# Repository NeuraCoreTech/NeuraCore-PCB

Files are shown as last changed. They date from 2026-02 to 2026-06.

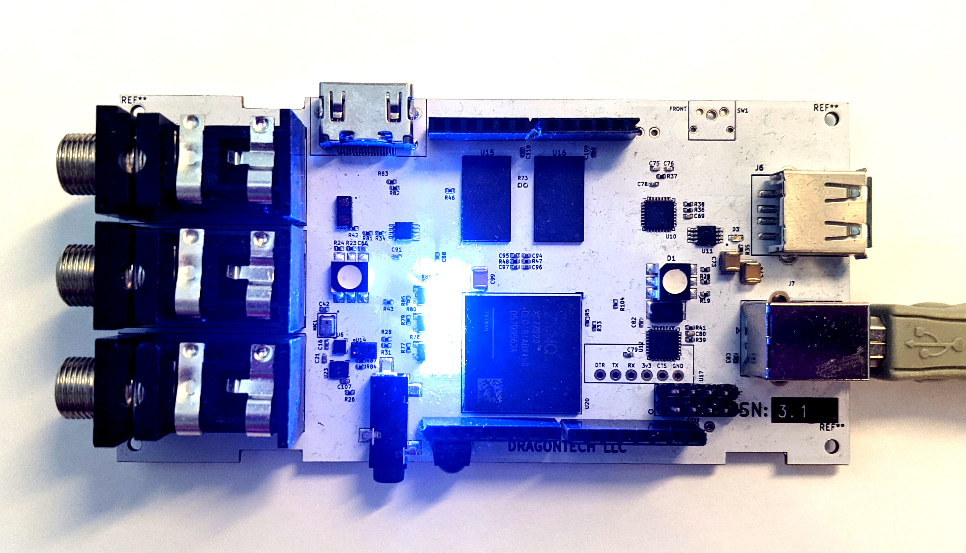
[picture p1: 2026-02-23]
V01/zynqPCB/images/dt01_v3_top.jpg

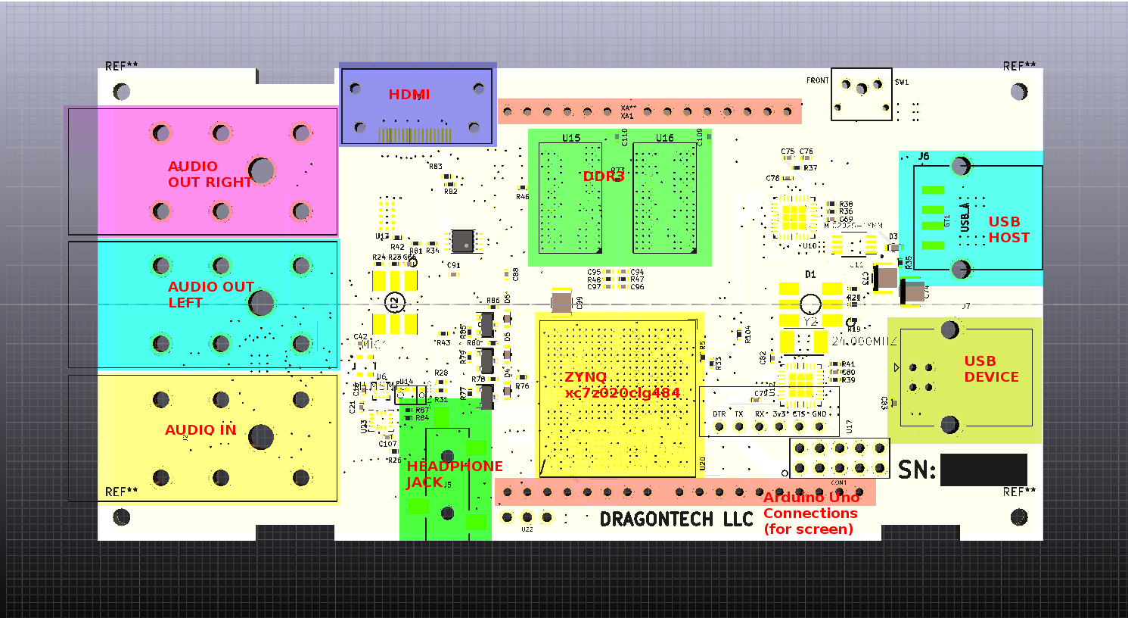
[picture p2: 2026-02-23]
V01/zynqPCB/images/blockdiagram_edited.png

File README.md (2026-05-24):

# FPGA Dev Board - Xilinx XC7Z020

Custom Zynq-7000 FPGA + ARM SoC development board based on the Xilinx XC7Z020-1CLG484I.

This repository contains the PCB design files, schematics, BOM, and hardware documentation for the board.

---

## Overview

This board is designed as a general-purpose Zynq development platform featuring:

- Xilinx XC7Z020 SoC
- DDR3L memory subsystem
- Gigabit Ethernet
- USB programming and UART interface
- USB OTG support
- QSPI boot flash
- Multi-rail power architecture
- FPGA PL expansion banks

The design targets embedded Linux, FPGA acceleration, digital design experimentation, and hardware/software co-design workflows.

---

## Hardware Features

### Processing System
- Xilinx XC7Z020-1CLG484I
- Dual-core ARM Cortex-A9
- FPGA programmable logic fabric

### Memory
- DDR3L memory interface
- Fly-by routed DDR topology
- Dedicated VTT termination rail

### Power Architecture
Power rails:
- 5V Input
- 3.3V
- 1.8V
- 1.35V
- 1.0V
- 0.675V DDR termination

Power sequencing implemented using:
- TPS56628 buck converters
- Dedicated PG sequencing
- Protection and filtering stages

### Connectivity
- Gigabit Ethernet (RTL8211F PHY)
- USB-C programming interface
- USB OTG via USB3320 ULPI PHY
- FT2232H for JTAG + UART

### Boot & Programming
- QSPI flash boot support
- Boot mode DIP switches
- Digilent HS3 compatible JTAG header

### FPGA I/O
- PL banks exposed for expansion
- HDMI-capable bank preparation
- Mixed-voltage IO support

---

## Repository Structure

```text
.
├── schematic/
├── pcb/
├── bom/
├── manufacturing/
├── images/
└── README.md
```

---

## Design Files

| File | Description |
|---|---|
| Schematic PDF | Complete board schematic |
| BOM | Bill of materials |
| PCB Layout | Board routing and placement |
| Gerbers | Manufacturing outputs |

---

## Key Components

| Component | Part |
|---|---|
| SoC | XC7Z020-1CLG484I |
| DDR3L | MT41K256M16TW |
| Ethernet PHY | RTL8211F-CG |
| USB PHY | USB3320 |
| USB/JTAG Interface | FT2232HL |
| QSPI Flash | W25Q512JVEIQ |

---

## Development Status

Current revision:
- v0.07

Status:
- Hardware prototype
- Under validation/testing

Known improvements and future revisions are documented within the schematic notes.

---

## Toolchain

Designed using:
- EasyEDA

Firmware/software targets:
- Vivado
- Vitis
- PetaLinux

---

## Bring-Up Checklist

- [ ] Verify all power rails
- [ ] Validate power sequencing
- [ ] DDR memory calibration
- [ ] QSPI boot validation
- [ ] JTAG connectivity test
- [ ] Ethernet PHY validation
- [ ] USB OTG validation

---

## Manufacturing Notes

Before fabrication:
- Verify impedance-controlled traces
- Review DDR length matching
- Validate power plane integrity
- Confirm connector footprints
- Review DFM constraints

---

## Contributors

- Krishna H. Patil
- Mohit Singh 
- Prajwal
- Arnav Yadnopavit

---
## Acknowledgements

This part of project (PCB) is heavily based on the open-source Zynq-7000 FPGA development board work by rehsd.

Original reference project:
https://github.com/rehsd/FPGA

Additional documentation and development notes:
https://www.rehsdonline.com/

The hardware architecture, schematic structure, and several subsystem implementations were adapted from the original project and modified for NeuraCoreTech requirements.

We thank rehsd for openly publishing the design resources and documentation.

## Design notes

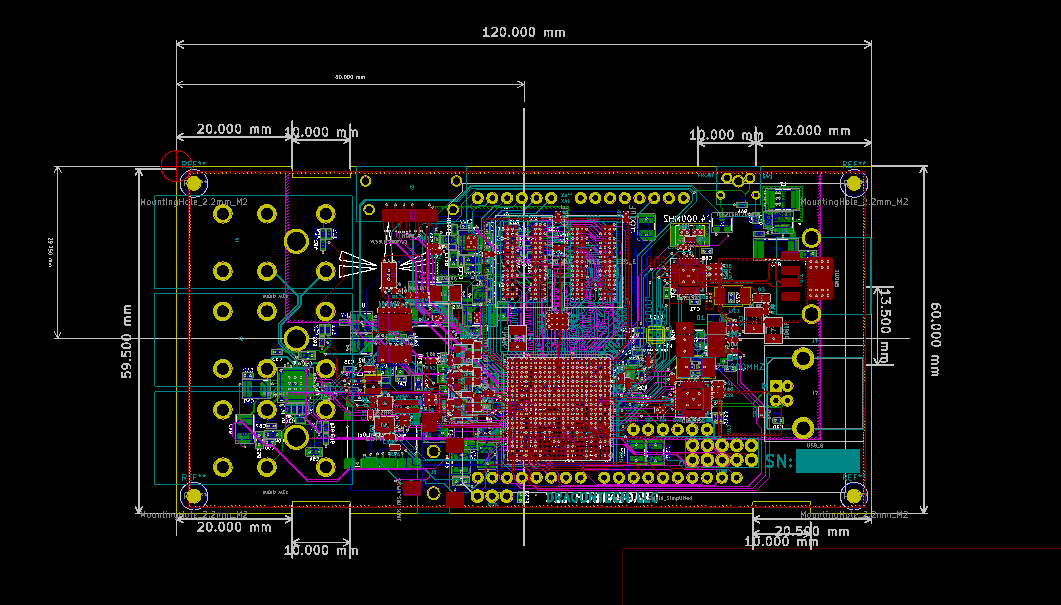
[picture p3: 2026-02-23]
V01/zynqPCB/images/dt01_schematic.PNG

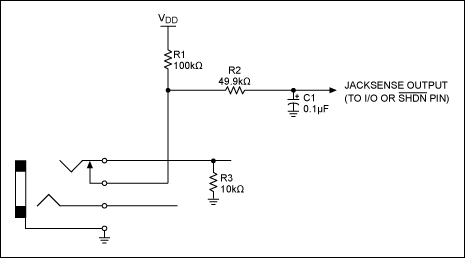
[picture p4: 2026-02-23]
V01/zynqPCB/docs/jackdetection.gif

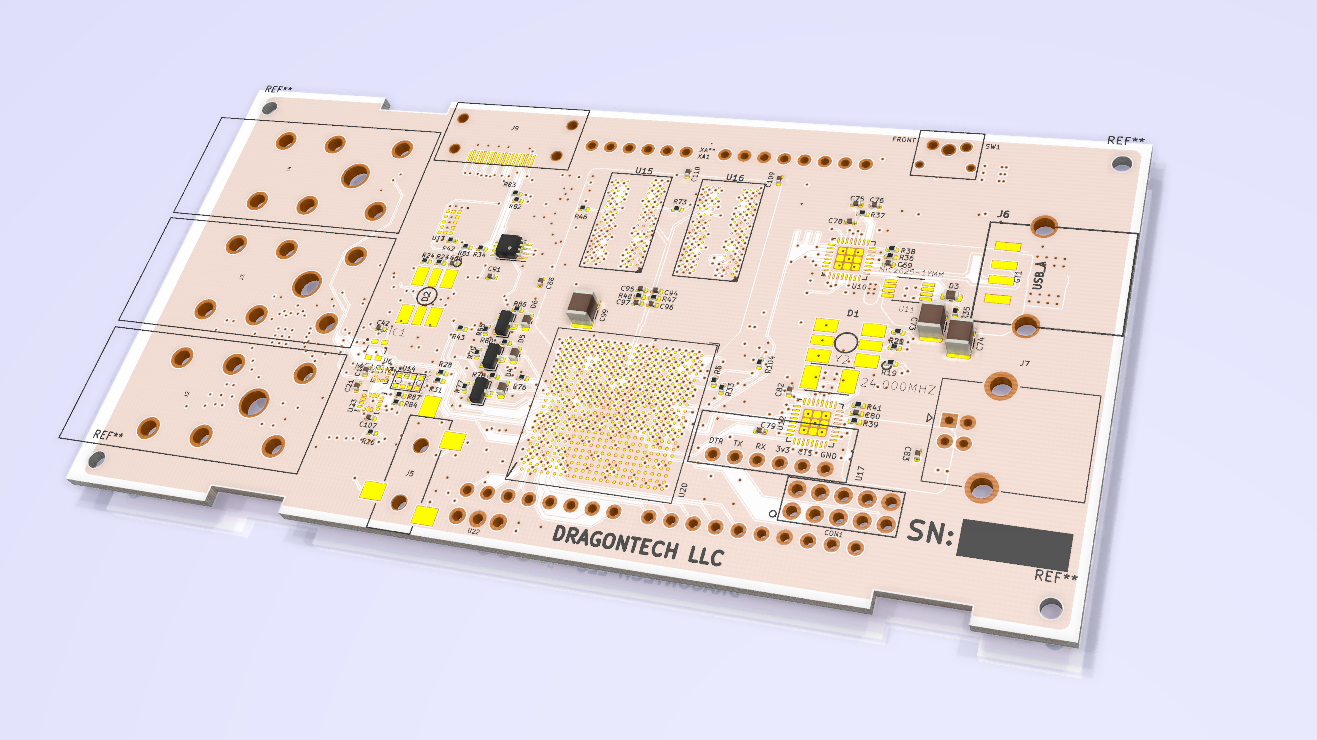
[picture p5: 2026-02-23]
V01/zynqPCB/images/dt01_3drender.PNG

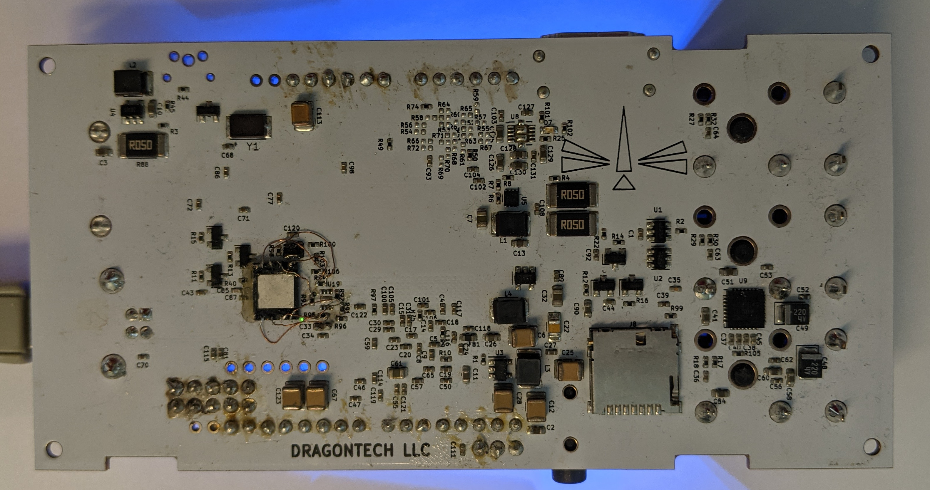
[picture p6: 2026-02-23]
V01/zynqPCB/images/dt01_v3_bottom.jpg

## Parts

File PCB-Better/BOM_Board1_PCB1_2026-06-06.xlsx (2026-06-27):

No. | Quantity | Comment | Designator | Footprint | Value | Manufacturer Part | Manufacturer | Supplier Part | Supplier
1 | 24 | 100nF | C1,C2,C3,C7,C12,C15,C20,C22,C23,C28,C31,C32,C144,C176,C183,C190,C191,C192,C193,C194,C195,C240,C241,C243 | C0603 | 100nF | C0603C104J5RAC | KEMET(基美) | C490602 | LCSC
2 | 53 | 4.7uF | C4,C5,C8,C13,C14,C19,C27,C30,C34,C42,C45,C46,C49,C52,C55,C58,C60,C62,C65,C73,C77,C78,C83,C85,C90,C91,C92,C93,C94,C155,C157,C159,C166,C168,C170,C181,C182,C184,C189,C218,C219,C221,C222,C227,C228,C229,C230,C244,C277,C278,C279,C280,C300 | C0603 | 4.7uF | CC0603KRX5R8BB475 | YAGEO(国巨) | C326580 | LCSC
3 | 6 | 47nF | C6,C35,C36,C37,C38,C39 | C0603 | 47nF
4 | 8 | 22uF | C9,C16,C17,C24,C25,C33,C217,C220 | C0603 | 22uF
5 | 4 | 10uF | C10,C11,C18,C26 | C0603 | 10uF
6 | 1 | 47pF | C21 | C0603 | 47pF
7 | 1 | 150pF | C29 | C0603 | 150pF
8 | 36 | 47nF | C40,C41,C43,C44,C48,C50,C51,C53,C54,C56,C57,C59,C63,C64,C66,C67,C68,C69,C70,C71,C80,C81,C82,C84,C86,C87,C88,C89,C96,C97,C98,C99,C100,C101,C102,C103 | C0402 | 47nF
9 | 22 | 470nF | C47,C61,C72,C74,C75,C76,C79,C95,C259,C264,C265,C268,C284,C285,C286,C293,C294,C295,C301,C302,C359,C360 | C0402 | 470nF
10 | 1 | 330uF | C248 | CAP-SMD_L7.3-W4.3-L-FD | 330uF | 10TPB330M | PANASONIC(松下) | C347551 | LCSC
11 | 10 | 100uF | C253,C257,C258,C262,C263,C287,C288,C289,C290,C291 | CAP-SMD_L3.5-W2.8-FD |  | 100uF | 湘怡中元/湘江 | C18185992 | LCSC
12 | 2 | 47uF | C261,C274 | CAP-SMD_L3.5-W2.8-FD |  | 47uF | 湘怡中元/湘江 | C18185992 | LCSC
13 | 16 | 100nF | C303,C349,C350,C351,C352,C353,C354,C355,C356,C357,C358,C361,C362,C363,C364,C365 | C0402 | 100nF
14 | 1 | 1nF 250V | C348 | C1206 | 1nF 250V | CC1206KRX7RYBB102 | YAGEO(国巨) |  | LCSC
15 | 14 | 100nF | C366,C367,C368,C369,C370,C371,C372,C373,C374,C375,C376,C377,C378,C379 | C0402 | 100nF |  |  | C1525
16 | 25 | 470nF | C380,C381,C382,C383,C384,C385,C386,C387,C388,C389,C390,C391,C392,C393,C394,C395,C396,C397,C398,C399,C400,C401,C402,C403,C404 | C0201 | 470nF | GRM033R60J474KE90D | muRata(村田) | C85926 | LCSC
17 | 1 | 100nF | C406 | C0201 | 100nF | CC0201KRX5R7BB104 | YAGEO(国巨) | C467016 | LCSC
18 | 1 | TF-01A | CARD2 | TF-SMD_TF-02 |  | TF-01A | Yuandi(元迪) | C2889258 | LCSC
19 | 1 | 10029449-111RLF | CN2 | HDMI-SMD_10029449-001RLF |  | 10029449-111RLF | Amphenol | C427307 | LCSC
20 | 9 | Zener Diode | D1,D2,D3,D4,D6,D7,D9,D10,D11 | D0402
21 | 3 | PMEG1030EJ,115 | D8,D12,D13 | SOD-323_L1.8-W1.3-LS2.5-RD |  | PMEG1030EJ,115 | Nexperia(安世) | C133633 | LCSC
22 | 1 | DC-005_2.0 | DC1 | DC-IN-TH_DC-5520-1
23 | 1 | 1206L050/15YR | F1 | F1206 |  | 1206L050/15YR | Littelfuse(美国力特) | C151162 | LCSC
24 | 1 | PTSLR12106V350 | F2 | F1210
25 | 2 | HDR | H2,H3 | HDR-TH_3P-P2.54-V-M-1 |  | HDR | BOOMELE(博穆精密) | C49257 | LCSC
26 | 1 | HDR | H4 | HDR-TH_2P-P2.54-V-M |  | HDR | XFCN(兴飞) | C492401 | LCSC
27 | 1 | PZ127-2-04-S | H5 | HDR-SMD_8P-P1.27-V-M-C2-C4-LS5.3 |  | PZ127-2-04-S | HCTL(华灿天禄) | C3975187 | LCSC
28 | 1 | Digilent JTAG-HS3 | HDR1 | HDR-SMD_14P-P2.54-V-M-R2-C7-LS7.4 |  | Digilent JTAG-HS3 | HCTL(华灿天禄) | C3294465 | LCSC
29 | 9 | MH2029-600Y | L2,L3,L4,L5,L6,L8,L9,L10,L12 | L0805 |  | MH2029-600Y | BOURNS | C780182 | LCSC
30 | 1 | 3.3uH | L11 | L0603 | 3.3uH | LQM18PN3R3MGHD | muRata(村田) | C2046254 | LCSC
31 | 8 | LED_0603-R | LED9,LED10,LED11,LED12,LED14,LED17,LED18,LED19 | LED0603-R-RD
32 | 2 | LED_0603-G | LED15,LED16 | LED0603-RD_GREEN
33 | 6 | T2N7002AK,LM | Q1,Q2,Q3,Q5,Q6,Q7 | SOT-23-3_L2.9-W1.3-P1.90-LS2.4-BR |  | T2N7002AK,LM | TOSHIBA(东芝) | C516175 | LCSC
34 | 1 | BSH103,215 | Q8 | TO-236AB_L2.9-W1.3-P0.95-LS2.3-BR |  | BSH103,215 | Nexperia(安世) | C329197 | LCSC
35 | 1 | 73.2kΩ | R1 | R0603 | 73.2kΩ | 0603WAF7322T5E | UNI-ROYAL(厚声) | C14890 | LCSC
36 | 4 | 22.1kΩ | R2,R7,R11,R15 | R0603 | 22.1kΩ | RC0603FR-0722K1L | YAGEO(国巨) | C137768 | LCSC
37 | 5 | 10kΩ | R3,R5,R9,R13,R176 | R0603 | 10kΩ | CR0603JA0103G | LIZ(丽智电子) | C101254 | LCSC
38 | 7 | 100kΩ | R4,R8,R12,R16,R70,R82,R125 | R0603 | 100kΩ | RC0603JR-07100KL | YAGEO(国巨) | C100048 | LCSC
39 | 1 | 30.1kΩ | R6 | R0603 | 30.1kΩ | RC0603FR-0730K1L | YAGEO(国巨) | C137745 | LCSC
40 | 1 | 17.4kΩ | R10 | R0603 | 17.4kΩ | 0603WAF1742T5E | UNI-ROYAL(厚声) | C22819 | LCSC
41 | 1 | 6.8kΩ | R14 | R0603 | 6.8kΩ | 0603WAJ0682T5E | UNI-ROYAL(厚声) | C26004 | LCSC
42 | 32 | 49.9Ω | R18,R19,R20,R21,R22,R23,R24,R25,R26,R27,R28,R29,R30,R31,R32,R33,R34,R35,R36,R44,R45,R54,R55,R60,R185,R186,R187,R188,R189,R190,R191,R192 | R0402 | 49.9Ω | RC0402FR-0749R9L | YAGEO(国巨) | C87044 | LCSC
43 | 12 | 500 | R37,R38,R40,R41,R42,R43,R53,R80,R126,R127,R128,R129 | R0603 | 500
44 | 8 | 1kΩ | R39,R52,R91,R92,R93,R130,R274,R277 | R0603 | 1kΩ | TR0603B1K00P0525Z | EVER OHMS(天二科技) | C188364 | LCSC
45 | 8 | 4.7kΩ | R46,R47,R48,R49,R50,R51,R63,R76 | R0603 | 4.7kΩ | CR0603FA4701G | LIZ(丽智电子) | C101062 | LCSC
46 | 8 | 22Ω | R56,R57,R58,R59,R74,R75,R85,R174 | R0603 | 22Ω | RC0603FR-0722RL | YAGEO(国巨) | C107701 | LCSC
47 | 2 | 240Ω | R61,R62 | R0603 | 240Ω | RC0603FR-07240RL | YAGEO(国巨) | C114613 | LCSC
48 | 2 | 100Ω | R64,R65 | R0603 | 100Ω | CR0603FA1000G | LIZ(丽智电子) | C100700 | LCSC
49 | 1 | 34.8kΩ | R69 | R0603 | 34.8kΩ | 0603WAF3482T5E | UNI-ROYAL(厚声) | C23141 | LCSC
50 | 1 | 2.49kΩ | R72 | R0603 | 2.49kΩ | RC0603FR-072K49L | YAGEO(国巨) | C108190 | LCSC
51 | 9 | 12kΩ | R73,R77,R78,R79,R81,R84,R124,R278,R279 | R0603 | 12kΩ | RC0603FR-0712KL | YAGEO(国巨) | C114659 | LCSC
52 | 5 | 20kΩ | R88,R89,R90,R272,R275 | R0603 | 20kΩ | RC0603DR-0720KL | YAGEO(国巨) | C137817 | LCSC
53 | 1 | DNP_1M | R131 | R0603 | DNP_1M
54 | 23 | 22Ω | R217,R218,R219,R220,R221,R222,R223,R231,R242,R243,R244,R255,R256,R257,R258,R259,R260,R261,R262,R263,R264,R265,R266 | R0402 | 22Ω | 0402WGJ0220TCE | UNI-ROYAL(厚声) | C25152 | LCSC
55 | 2 | 500 | R224,R225 | R0402 | 500
56 | 2 | 12kΩ | R226,R234 | R0402 | 12kΩ | RC0402FR-0712KL | YAGEO(国巨) | C114760 | LCSC
57 | 1 | 47kΩ | R227 | R0402 | 47kΩ | RC0402JR-0747KL | YAGEO(国巨) | C163440 | LCSC
58 | 1 | 200Ω | R228 | R0402 | 200Ω | RC0402FR-07200RL | YAGEO(国巨) | C114764 | LCSC
59 | 9 | 4.7kΩ | R229,R230,R235,R239,R240,R241,R251,R252,R254 | R0402 | 4.7kΩ | RMC04024.7K5%N | Tyohm(幸亚电阻) | C269679 | LCSC
60 | 6 | 1kΩ | R232,R245,R246,R247,R248,R249 | R0402 | 1kΩ | RC0402JR-071KL | YAGEO(国巨) | C105637 | LCSC
61 | 1 | 8.06kΩ | R233 | R0402 | 8.06kΩ | RC0402FR-078K06L | YAGEO(国巨) | C276278 | LCSC
62 | 3 | 510Ω | R236,R237,R238 | R0402 | 510Ω | RC0402FR-07510RL | YAGEO(国巨) | C276273 | LCSC
63 | 1 | 2.49kΩ | R250 | R0402 | 2.49kΩ | 0402WGF2491TCE | UNI-ROYAL(厚声) | C25884 | LCSC
64 | 1 | DNP_4.7K | R253 | R0402 | DNP_4.7K
65 | 1 | 100Ω | R267 | R0201 | 100Ω | RC0201FR-07100RL | YAGEO(国巨) | C77623 | LCSC
66 | 2 | 20kΩ | R268,R269 | R0402 | 20kΩ | RC0402JR-0720KL | YAGEO(国巨) | C137902 | LCSC
67 | 2 | 0 | R270,R271 | R0603 | 0
68 | 2 | DNP_0R | R273,R276 | R0603 | DNP_0R
69 | 1 | HR911130A | RJ1 | RJ45-TH_HR911130A |  | HR911130A | HANRUN(汉仁) | C54408 | LCSC
70 | 2 | Key_SMD_6x6x6.5 | SW1,SW2 | SW-SMD_4P-L6.0-W6.0-P4.50-LS9.0-2
71 | 1 | SMXS-03K-TP | SW4 | SW-SMD_SMXS-03K-TP |  | SMXS-03K-TP | SM Switch | C5439762 | LCSC
72 | 2 | MT41K256M16TW-107:P | U1,U3 | FBGA-96_L14.0-W8.0-R16-C6-P0.80-TL |  | MT41K256M16TW-107:P | micron(镁光) | C253882 | LCSC
73 | 1 | XC7Z020-1CLG484I | U2 | FBGA-484_L19.0-W19.0-R22-C22-P0.80-TL |  | XC7Z020-1CLG484I | XILINX(赛灵思) | C89055 | LCSC
74 | 4 | TPS56628DDAR | U4,U6,U8,U10 | SOIC-8_L4.9-W3.9-P1.27-LS6.0-BL-EP |  | TPS56628DDAR | TI(德州仪器) | C485522 | LCSC
75 | 1 | GT-USB-7010ASV | U27 | USB-C-SMD_G-SWITCH_GT-USB-7010ASV |  | GT-USB-7010ASV | G-Switch(品赞) | C2988369 | LCSC
76 | 5 | Standoff 3.0mm | U28,U29,U30,U31,U71 | Standoff 3.0mm
77 | 1 | FT2232HL-REEL | U34 | LQFP-64_L10.0-W10.0-P0.50-LS12.0-TL |  | FT2232HL-REEL | FTDI(飞特帝亚) | C27882 | LCSC
78 | 1 | RTL8211F-CG | U35 | WQFN-40_L5.0-W5.0-P0.4-BL-EP |  | RTL8211F-CG | REALTEK(瑞昱) | C187932 | LCSC
79 | 1 | USB3320C-EZK | U36 | QFN-32_L5.0-W5.0-P0.50-BL-EP3.4 |  | USB3320C-EZK | MICROCHIP(美国微芯) | C52447 | LCSC
80 | 3 | 2.2uH AIP0530GX-2R2MPBDG | U37,U38,U39 | Inductor 5.7mm X 5.4mm
81 | 1 | 3.3uH AIP0530GX-3R3MPBDG | U40 | Inductor 5.7mm X 5.4mm
82 | 2 | EBBI 68 Plug - 716612568 | U44,U45 | EBBI 68 Plug - 716612568
83 | 1 | 93LC56B-I/SN | U60 | SOIC-8_L5.0-W4.0-P1.27-LS6.0-BL |  | 93LC56B-I/SN | MICROCHIP(美国微芯) | C183620 | LCSC
84 | 1 | SN74LVC1G07DBVT | U61 | SOT-23-5_L2.9-W1.6-P0.95-LS2.8-BR |  | SN74LVC1G07DBVT | TI(德州仪器) | C2867373 | LCSC
85 | 1 | W25Q512JVEIQ | U63 | WSON-8_L8.0-W6.0-P1.27-TL-EP |  | W25Q512JVEIQ | WINBOND(华邦) | C3034691 | LCSC
86 | 2 | Standoff 2.0mm | U64,U65 | Standoff 2.0mm
87 | 1 | BD3539FVM-TR | U68 | MSOP-8_L2.9-W2.8-P0.65-LS4.0-BL |  | BD3539FVM-TR | ROHM(罗姆) | C213437 | LCSC
88 | 1 | 25MHz | U70 | OSC-SMD_4P-L2.5-W2.0-BL-1 | 25MHz | ECS-2520MVQ-250-CN-TR | ECS | C2595926 | LCSC
89 | 1 | 13MHz | U72 | OSC-SMD_4P-L2.5-W2.0-BL | 13MHz | ECS-2520MV-130-BN-TR | ECS | C2613032 | LCSC
90 | 1 | MIC2099-1YMT-TR | U73 | UDFN-6_L1.6-W1.6-P0.50-BL-EP1.2 |  | MIC2099-1YMT-TR | MICROCHIP(美国微芯) | C621526 | LCSC
91 | 1 | TXS02612RTWR | U74 | WQFN-24_L4.0-W4.0-P0.50-TL-EP2.5 |  | TXS02612RTWR | TI(德州仪器) | C140276 | LCSC
92 | 1 | TPD12S016PWR | U78 | TSSOP-24_L7.8-W4.4-P0.65-LS6.4-BL |  | TPD12S016PWR | TI(德州仪器) | C201665 | LCSC
93 | 2 | 47uF | U79,U80 | CAP-SMD_L7.3-W4.3-RD | 47uF | T494D476M025AT | KEMET(基美) | C1954708 | LCSC
94 | 1 | 678038020 | USB1 | MICRO-USB-SMD_MOLEX_678038020 |  | 678038020 | MOLEX | C564922 | LCSC
95 | 1 | 12MHz ECS-2520MV-120-BN-TR | X1 | OSC-SMD_4P-L2.5-W2.0-BL | 12MHz ECS-2520MV-120-BN-TR | ECS-2520MV-120-BN-TR | ECS |  | LCSC
96 | 1 | 33.3MHz ECS-2520MV-333.3-BN-TR | X2 | OSC-SMD_4P-L2.5-W2.0-BL | 33.3MHz ECS-2520MV-333.3-BN-TR | ECS-2520MV-120-BN-TR | ECS |  | LCSC

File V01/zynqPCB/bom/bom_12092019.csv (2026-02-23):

Refs | Value | Footprint | Quantity | MFR | MPN | SPR | SPN
Y1;Y2 | 24.000MHZ | ABM3-12.000MHZ-B2-T:XTAL500X320X130N | 2 | Abracon LLC | ABM3-24.000MHZ-D2Y-T | DigiKey | 535-10643-2-ND
C106;C105;C98;C93;C109;C110;C120;C111 | .01uF | Capacitor_SMD:C_0402_1005Metric | 8 | Murata | GRM155R71H103KA88J | Digikey | 490-6351-1-ND
C68;C70;C71;C77;C72;C79;C81;C82;C86;C131;C97;C96;C95;C94;C88;C16;C107;C36;C64;C63;C52;C56;C53;C62;C39 | .1uF | Capacitor_SMD:C_0402_1005Metric | 25 | Murata | GRM188R71C104KA01D | Digikey | 490-1532-1-ND
C65;C78;C87;C34;C18;C17;C15;C14;C29;C30;C31;C23;C8;C4;C1;C108;C116;C117;C118;C119;C104;C103;C102;C101;C121;C55;C50;C47;C46 | .47uF | Capacitor_SMD:C_0402_1005Metric | 29 | Murata | GRM188R71C474KA88D | Digikey | 490-3295-1-ND
C76;C75;C85;C84 | 18pF | Capacitor_SMD:C_0402_1005Metric | 4 | Murata | GCM1555C1H180JA16D | Digikey | 490-12650-1-ND
C91;C92;C37;C40;C38;C45;C43;C44 | 1uF | Capacitor_SMD:C_0402_1005Metric | 8 | Murata | GRM188R71C105KE15D | Digikey | 490-10734-1-ND
C69;C80;C35 | 2.2uF | Capacitor_SMD:C_0402_1005Metric | 3 | Murata | GRM155R61A225KE95D | Digikey | 490-10451-1-ND
C66;C83;C20;C19;C24;C27;C9;C5;C114;C115;C100;C127;C122;C89;C21;C42;C59;C57 | 4.7uF | Capacitor_SMD:C_0402_1005Metric | 18 | Murata | GRM21BR61A475KA73L | Digikey | 490-9750-1-ND
C3;C13;C2;C10;C11;C26;C33;C126;C125;C130;C129;C128;C90;C54;C58;C51;C41;C60 | 10uF | Capacitor_SMD:C_0603_1608Metric | 18 | Murata | GRM21BR61A106KE19L | Digikey | 490-1709-1-ND
FB1 | 120R, 100 MHz, size 0603 | Capacitor_SMD:C_0603_1608Metric | 1 | Murata Electronics | BLM18AG121SN1D | Digikey | 490-1011-1-ND
D3;D5;D4;D6;D7 | BLUE LED | Capacitor_SMD:C_0603_1608Metric | 5 | Vishay Semiconductors | VLMB1300-GS08 | Digikey | VLMB1300-GS08CT-ND
C32;C7;C61 | 47uF | Capacitor_SMD:C_0805_2012Metric | 3 | Murata Manufacturing Co Ltd | GRM32ER70J476ME20L | Digikey | 490-6542-1-ND
C22 | 330uF | Capacitor_SMD:C_1206_3216Metric | 1 | AVX Corporation | F950G337MAAAQ2 | Digikey | 478-8378-1-ND
C67;C73;C74;C28;C25;C12;C6;C99;C123 | 100uF | Capacitor_SMD:C_1210_3225Metric | 9 | TAIYO YUDEN | JMK325ABJ107MM-P | Digikey | 587-4313-1-ND
C113 | 47uF | Capacitor_SMD:C_1210_3225Metric | 1 | Murata Manufacturing Co Ltd | GRM32ER70J476ME20L | Digikey | 490-6542-1-ND
L2;L3;L4;L1 | 2.2uH | Capacitor_SMD:C_1812_4532Metric | 4 | Murata | LQH43PN2R2M26L | Digikey | 490-12049-1-ND
C49;C48 | 220uF Tant. | Capacitor_Tantalum_SMD:CP_EIA-3528-12_Kemet-T | 2 | AVX Corporation | F930G227KBA | Digikey | 478-8139-1-ND
J7 | USB_B | Connector_USB:USB_B_OST_USB-B1HSxx_Horizontal | 1 | On Shore Technology | USB-B1HSW6 | Digikey | ED2982-ND
J9 | HDMI_A | DFTcustom:10029449-111RLF | 1 | Amphenol ICC | 10029449-111RLF | Digikey | 609-4614-1-ND
J8 | Micro_SD_Card_Det | DFTcustom:AMPHENOL-114-00841-68 | 1 | Amphenol ICC | 114-00841-68 | Digikey | 114-00841-68-1-ND
U14 | APDS-9960 | DFTcustom:APDS_9960 | 1 | Broadcom Limited | APDS-9960 | Digikey | 516-3480-1-ND
XA1 | Arduino_Uno_Shield_Simplified | DFTcustom:Arduino_Uno_Shield_Simplified | 1 | DNS | - | - | -
U20 | xc7z020clg484 | DFTcustom:BGA-484_19.0x19.0mm_Layout22x22_P0.80mm_dia0.40mm | 1 | Xilinx | XC7Z020-1CLG484C | Digikey | 122-1850-ND
U15;U16 | MT41K256M16HA-125_E | DFTcustom:FBGA-96-DDR3-SDRAM | 2 | Micron | MT41K256M16TW-107 | Digikey | 557-2006-6-ND
U17 | FTDITypeUART | DFTcustom:FTDI_CONN | 1 | DNS | - | - | -
U22 | TSOP344 | DFTcustom:JUMPER_3PIN | 1 | Vishay Semiconductor | TSOP34438 | Digikey | TSOP34438-ND
U13 | VL53L1CXV0FY/1 | DFTcustom:Optical_LGA12 | 1 | STMicroelectronics | VL53L1CXV0FY/1 | Digikey | 497-17764-2-ND
D1;D2 | LED_RGB | DFTcustom:PLCC6-SM-RGB-LED | 2 | Cree, Inc. | CLP6C-FKB-CM1Q1H1BB7R3R3 | Digikey | CLP6C-FKB-CM1Q1H1BB7R3R3CT-ND
J4;J3;J2 | AUDIO JACK | DFTcustom:RA49C14B | 3 | Switchcraft Conxall | RA49C12B | Digikey | SC2083-ND
J5 | JACK_TRS_4PINS | DFTcustom:SJ-352X-SMT | 1 | CUI Inc. | SJ-3524-SMT-TR | Digikey | CP-3524SJCT-ND
J6 | USB_A | DFTcustom:USB-A-Receptacle-FCI_87583 | 1 | Amphenol ICC | 87583-2010RLF | Digikey | 609-5390-1-ND
MIC1 | MEMSMIC | DFTcustom:WM7121PE | 1 | Cirrus Logic | WM7121PIMSE/RV | Digikey | WM7121PIMSE/RVCT-ND
U19 | S25FL256SAGNFI001 | DFTcustom:WSON-8 | 1 | Cypress | S25FL256SAGNFI001 | Digikey | 1274-1005-ND
CON1 | AVR-JTAG-10 | DFTcustom:XilinxJTAG | 1 | DNS
GT1 | GNDTIE | DFTcustom:gndtie | 1 | DNS | - | - | -
SW1 | TL6215RF200BDT | DFTcustom:tl6215_right_angle | 1 | E-Switch Inc | TL6215RF200BDT | Digikey | EG5162-ND
U10;U12 | USB3320 | Package_DFN_QFN:QFN-32-1EP_5x5mm_P0.5mm_EP3.1x3.1mm | 2 | Microchip Technology | USB3320C-EZK-TR | Digikey | USB3320C-EZK-CT-NDs
U9 | TLV320AIC3104 | Package_DFN_QFN:QFN-32-1EP_5x5mm_P0.5mm_EP3.65x3.65mm | 1 | Texas Instruments | TLV320AIC3104IRHBR | Digikey | 296-26818-1-ND
U6 | LIS2HH12 | Package_LGA:LGA-12_2x2mm_P0.5mm | 1 | STMicroelectronics | LIS2HH12TR | Digikey | 497-15069-1-ND
U23 | LSM6DS3 | Package_LGA:LGA-14_3x2.5mm_P0.5mm_LayoutBorder3x4y | 1 | STMicroelectronics | LSM6DS3TR | Digikey | 497-15383-1-ND
U21 | PCA9306 | Package_SO:SSOP-8_2.95x2.8mm_P0.65mm | 1 | Texas Instruments | PCA9306DCTR | Digikey | 296-18509-2-ND
U8 | TPS51200DRCR | Package_SON:VSON-10-1EP_3x3mm_P0.5mm_EP1.65x2.4mm_ThermalVias | 1 | Texas Instruments | TPS51200DRCR | Digikey | 296-26978-1-ND
U5 | TLV62080DSGx | Package_SON:WSON-8-1EP_2x2mm_P0.5mm_EP0.9x1.6mm | 1 | Texas Instruments | TLV62080DSGR | Digikey | 296-39270-6-ND
Q9;Q8;Q10;Q7;Q5;Q3;Q1;Q6;Q4;Q2 | IRLML2502 | Package_TO_SOT_SMD:SOT-23 | 10 | Infineon Technologies AG | IRLML2502TRPBF | Digikey | IRLML2502PBFCT-ND
U3 | SC189 - 1.0V | Package_TO_SOT_SMD:SOT-23-5 | 1 | Semtech Corporation | SC189ASKTRT | Digikey | SC189ASKCT-ND
U7 | SC189 - 1.8V | Package_TO_SOT_SMD:SOT-23-5 | 1 | Semtech Corporation | SC189LSKTRT | Digikey | SC189LSKCT-ND
U4 | SC189 - 3.3V | Package_TO_SOT_SMD:SOT-23-5 | 1 | Semtech Corporation | SC189ZSKTRT | Digikey | SC189ZSKCT-ND
U1;U2 | LM3880 | Package_TO_SOT_SMD:SOT-23-6 | 2 | Texas Instruments | LM3880MF-1AE/NOPB | Digikey | LM3880MF-1AE/NOPBDKR-ND
R19;R20;R15;R13;R11;R22;R23;R16;R14;R12 | 100 | Resistor_SMD:R_0402_1005Metric | 10 | Yageo | RC0402FR-07100RL | Digikey | 311-100LRCT-ND
R1;R2;R3;R4;R5;R34;R81;R101;R27;R29;R17;R28 | 100k | Resistor_SMD:R_0402_1005Metric | 12 | Yageo | RC0402FR-07100KL | Digikey | 311-100KLRTR-ND
R36;R39;R33;R6;R42;R43;R44 | 10k | Resistor_SMD:R_0402_1005Metric | 7 | Yageo | RC0402FR-0710KL | Digikey | 311-10.0KLRTR-ND
R48;R47 | 10k 1% | Resistor_SMD:R_0402_1005Metric | 2 | Yageo | RC0402FR-0710KL | Digikey | 311-10.0KLRCT-ND
R35;R80;R78;R86;R102;R45;R21;R24 | 150 | Resistor_SMD:R_0402_1005Metric | 8 | Yageo | RC0402FR-07150RL | Digikey | 311-150LRTR-ND
R37;R40 | 1M | Resistor_SMD:R_0402_1005Metric | 2 | Yageo | RC0402FR-071ML | Digikey | 311-1.00MLRCT-ND
R79;R77;R85;R105 | 1k | Resistor_SMD:R_0402_1005Metric | 4 | Yageo | RC0402FR-071KL | Digikey | 311-1.00KLRCT-ND
R25;R96;R97;R95;R91;R92;R93;R94;R106 | 20k | Resistor_SMD:R_0402_1005Metric | 9 | Yageo | RT0402BRD0720KL | Digikey | YAG1388CT-ND
R100 | 24.9 1% | Resistor_SMD:R_0402_1005Metric | 1 | Yageo | RC0402FR-0724K9L | Digikey | 311-24.9KLRTR-ND
R7;R49;R46 | 240 1% | Resistor_SMD:R_0402_1005Metric | 3 | Yageo | RC0402FR-07240RL | Digikey | 311-240LRTR-ND
R9;R10;R8;R82;R83;R74;R98;R103;R104 | 4.7k | Resistor_SMD:R_0402_1005Metric | 9 | Yageo | RC0402JR-074K7L | Digikey | 311-4.7KJRCT-ND
R52;R51;R54;R53;R56;R55;R58;R57;R60;R59;R62;R61;R64;R63;R66;R65;R67;R68;R69;R70;R71;R72;R73 | 40.2 1% | Resistor_SMD:R_0402_1005Metric | 23 | Yageo | RC0402FR-0740R2L | Digikey | 311-40.2LRTR-ND
R26;R84;R87 | 47 | Resistor_SMD:R_0402_1005Metric | 3 | Yageo | RC0402JR-0747RL | Digikey | 311-47JRTR-ND
R99 | 47k | Resistor_SMD:R_0402_1005Metric | 1 | Yageo | RC0402FR-0747KL | Digikey | 311-47.0KLRTR-ND
R32;R30;R18;R31 | 49.9k | Resistor_SMD:R_0402_1005Metric | 4 | Yageo | RC0402FR-0749K9L | Digikey | 311-49.9KLRCT-ND
R38;R41 | 8.06k 1% | Resistor_SMD:R_0402_1005Metric | 2 | Yageo | RC0402FR-078K06L | Digikey | 311-8.06KLRTR-ND
R50;R75;R76 | 80.6 1% | Resistor_SMD:R_0402_1005Metric | 3 | Yageo | RC0402FR-0780R6L | Digikey | 311-80.6LRTR-ND
R90;R88;R89 | .05 | Resistor_SMD:R_2512_6332Metric | 3 | Bourns Inc | CRA2512-FZ-R050ELF | Digikey | CRA2512-FZ-R050ELFCT-ND
U11 | MIC2025-1YMM | SOP65P490X110-8N:SOP65P490X110-8N | 1 | Microchip | MIC2025-1YMM-TR | Digikey | MIC2025-1YMM-CT-ND
U18 | ABRACON-ASDMB | XTAL_ASDMB-24.000MHZ-LC-T:XTAL_ASDMB-24.000MHZ-LC-T | 1 | Abracon LLC | ASDMB-24.000MHZ-LC-T | Digikey | 535-11728-1-ND

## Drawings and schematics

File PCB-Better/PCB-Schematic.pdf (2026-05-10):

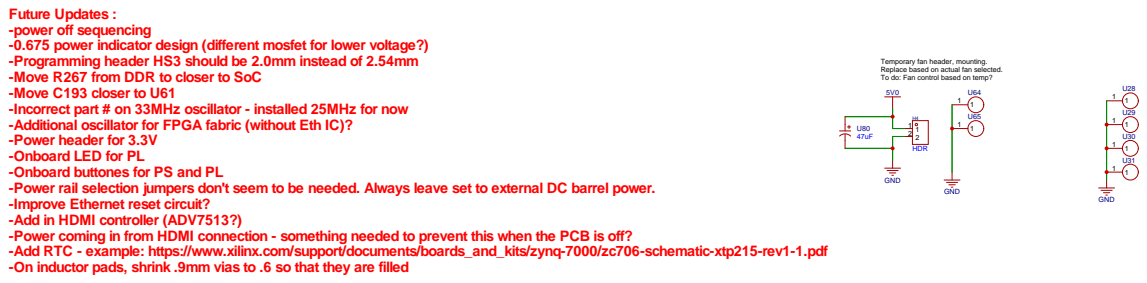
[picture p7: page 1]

Future Updates :
-power off sequencing
-0.675 power indicator design (different mosfet for lower voltage?)
-Programming header HS3 should be 2.0mm instead of 2.54mm
-Move R267 from DDR to closer to SoC
-Move C193 closer to U61
-Incorrect part # on 33MHz oscillator - installed 25MHz for now
-Additional oscillator for FPGA fabric (without Eth IC)?
-Power header for 3.3V
-Onboard LED for PL
-Onboard buttones for PS and PL
-Power rail selection jumpers don't seem to be needed. Always leave set to external DC barrel power.
-Improve Ethernet reset circuit?
-Add in HDMI controller (ADV7513?)
-Power coming in from HDMI connection - something needed to prevent this when the PCB is off?
-Add RTC - example: https://www.xilinx.com/support/documents/boards_and_kits/zynq-7000/zc706-schematic-xtp215-rev1-1.pdf
-On inductor pads, shrink .9mm vias to .6 so that they are filled

Temporary fan header, mounting.
Replace based on actual fan selected.
To do: Fan control based on temp?

DC Barrel,

# PWR Select

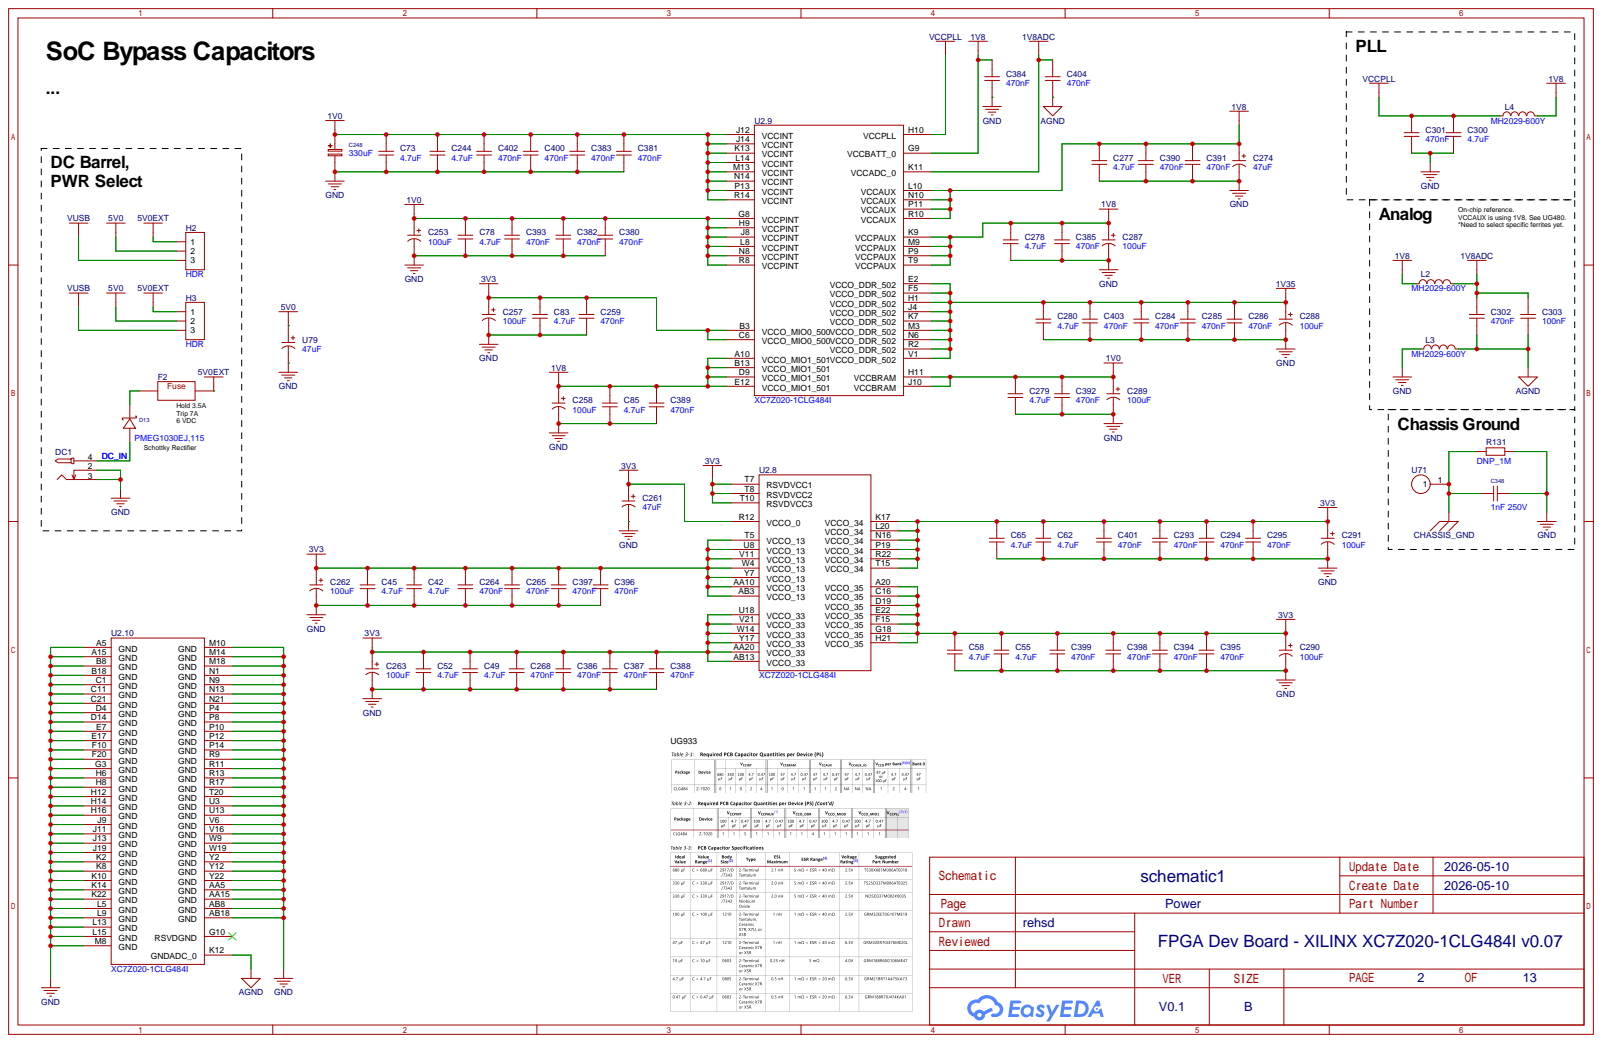
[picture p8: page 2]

VCCINT R14 VCCINT P13 VCCINT N14 VCCINT M13 VCCINT L14 VCCINT K13 VCCINT J14 VCCINT J12

VCCPINT R8 VCCPINT N8 VCCPINT L8 VCCPINT J8 VCCPINT H9 VCCPINT G8

On-chip reference.
VCCAUX is using 1V8. See UG480.
*Need to select specific ferrites yet.

VCCPAUX T9 VCCPAUX P9 VCCPAUX M9 VCCPAUX K9

GND A15 GND A5
GND M8 GND L15 GND L13 GND L9 GND L5 GND K22 GND K14 GND K10 GND K8 GND K2 GND J19 GND J13 GND J11 GND J9 GND H16 GND H14 GND H12 GND H8 GND H6 GND G3 GND F20 GND F10 GND E17 GND E7 GND D14 GND D4 GND C21 GND C11 GND C1 GND B18 GND B8

# Buck Converters

# Sequence: 1V0, 1V8, 1V35, 3V3

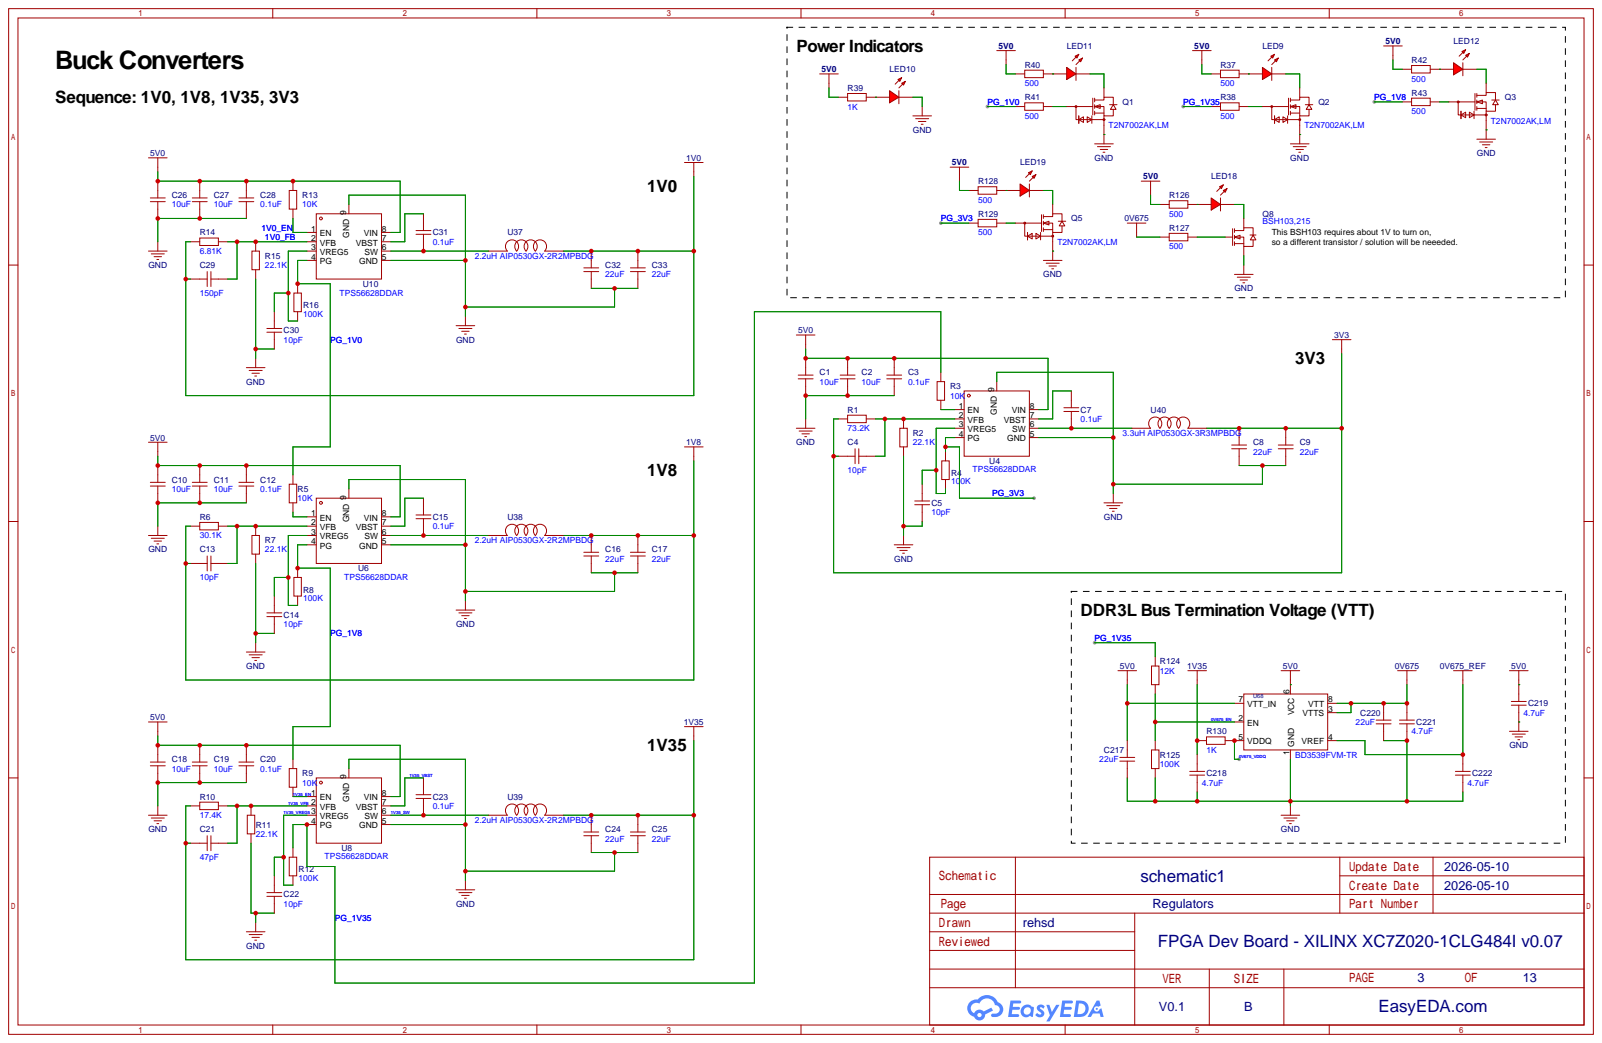
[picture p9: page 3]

BSH103,215
This BSH103 requires about 1V to turn on,
so a different transistor / solution will be neeeded.

DDR3L Bus Termination Voltage (VTT)

# Programming

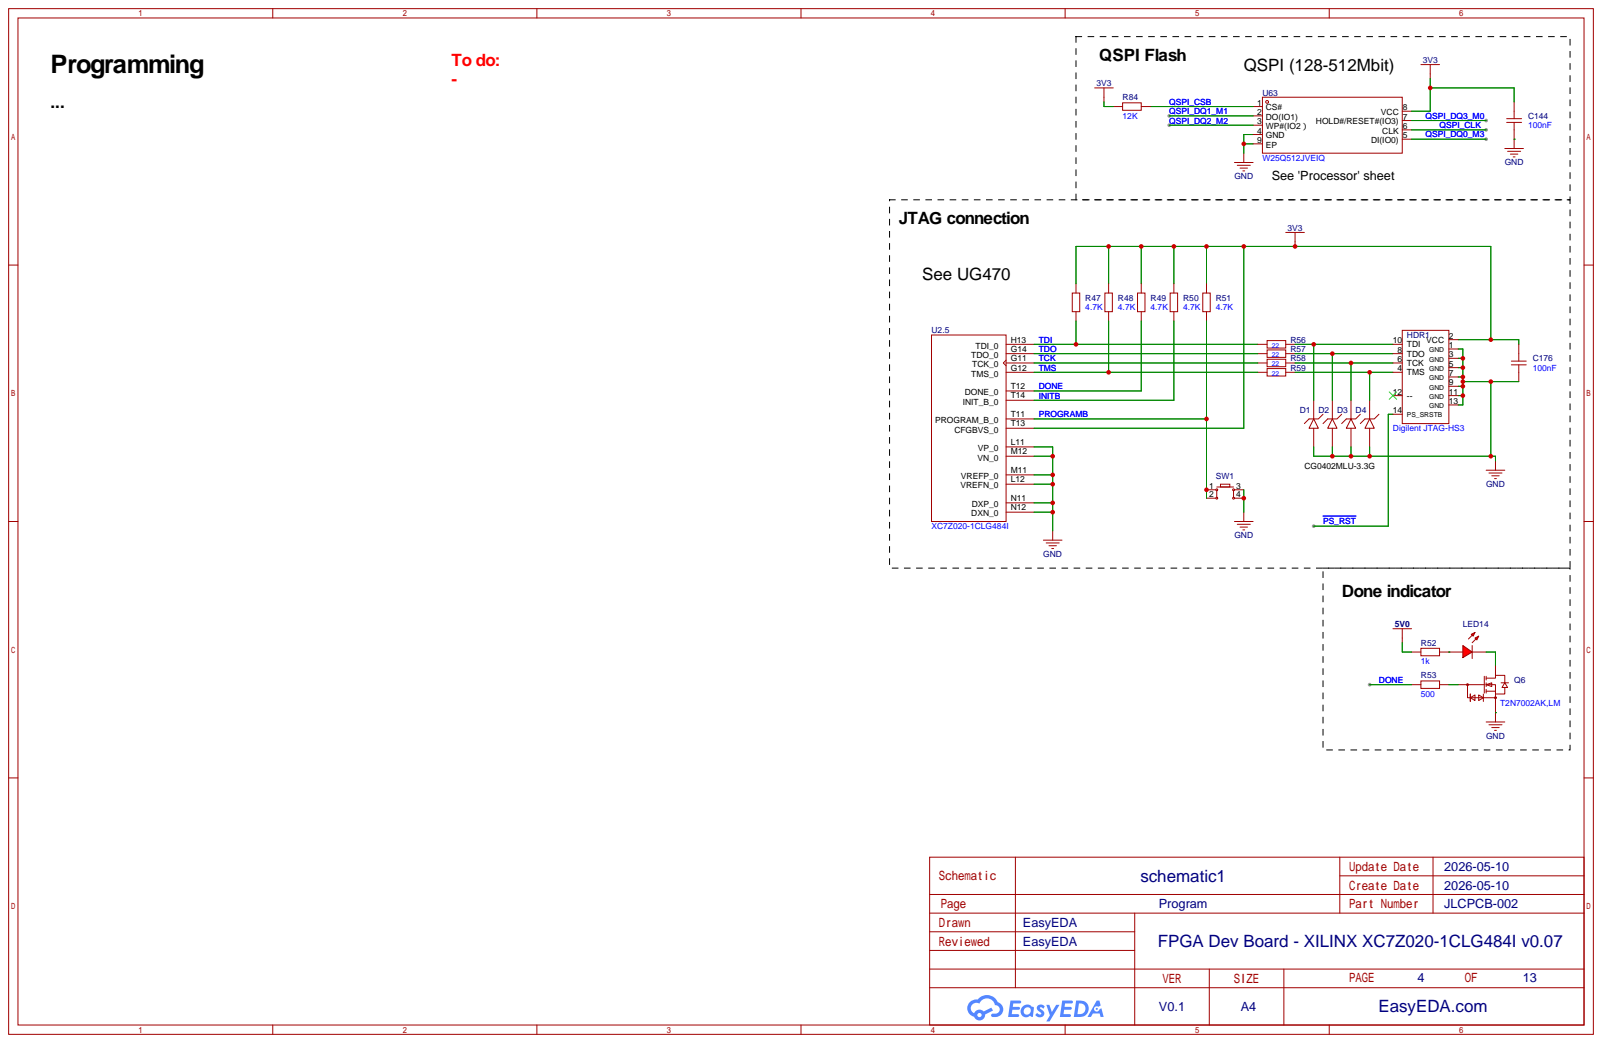
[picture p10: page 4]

PS_DDR_DQ31_502 Y1 PS_DDR_DQ30_502 W3 PS_DDR_DQ29_502 Y3 PS_DDR_DQ28_502 W1 PS_DDR_DQ27_502 U2 PS_DDR_DQ26_502 AA1 PS_DDR_DQ25_502 U1 PS_DDR_DQ24_502 AA3 PS_DDR_DQ23_502 R1 PS_DDR_DQ22_502 M2 PS_DDR_DQ21_502 T2 PS_DDR_DQ20_502 R3 PS_DDR_DQ19_502 T1 PS_DDR_DQ18_502 N3 PS_DDR_DQ17_502 T3 PS_DDR_DQ16_502 M1 PS_DDR_DQ15_502 K3 PS_DDR_DQ14_502 J1 PS_DDR_DQ13_502 K1 PS_DDR_DQ12_502 L3 PS_DDR_DQ11_502 L2 PS_DDR_DQ10_502 L1 PS_DDR_DQ9_502 G1 PS_DDR_DQ8_502 G2 PS_DDR_DQ7_502 F1 PS_DDR_DQ6_502 F2 PS_DDR_DQ5_502 E1 PS_DDR_DQ4_502 E3 PS_DDR_DQ3_502 D3 PS_DDR_DQ2_502 B2 PS_DDR_DQ1_502 C3 PS_DDR_DQ0_502 D1

# DDR3L

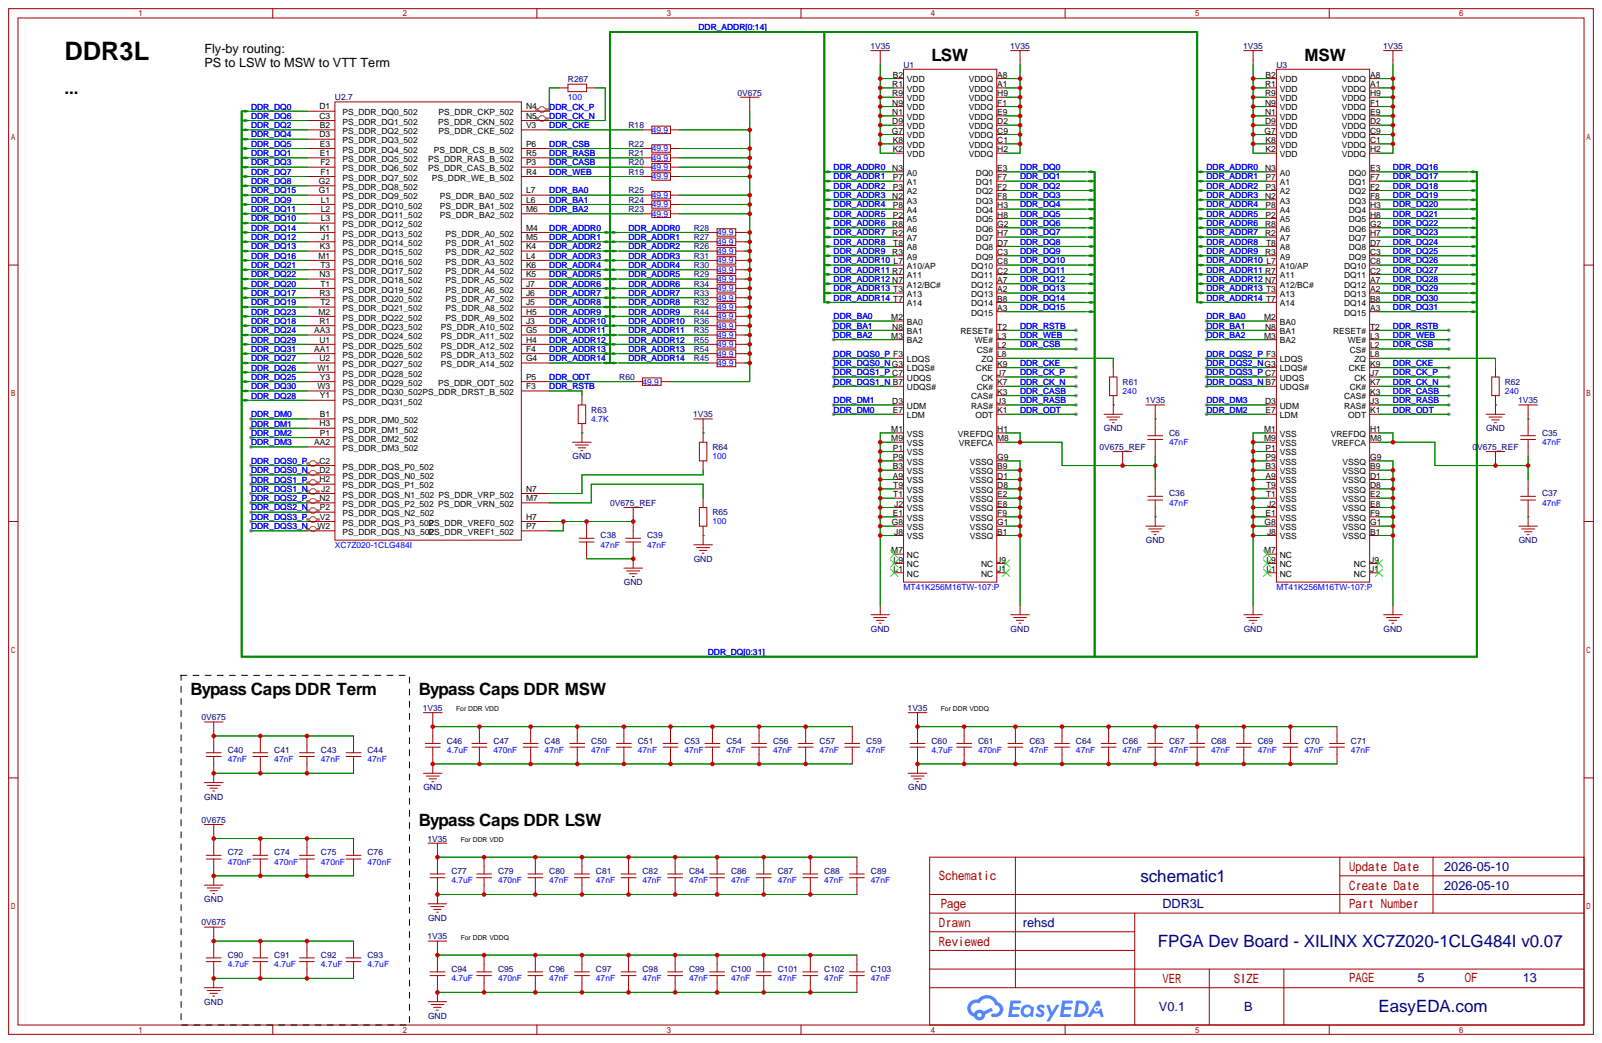
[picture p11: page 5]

Fly-by routing:
PS to LSW to MSW to VTT Term

Bypass Caps DDR Term

Bypass Caps DDR MSW

GND
Bypass Caps DDR LSW

# USB

# Programming, Serial

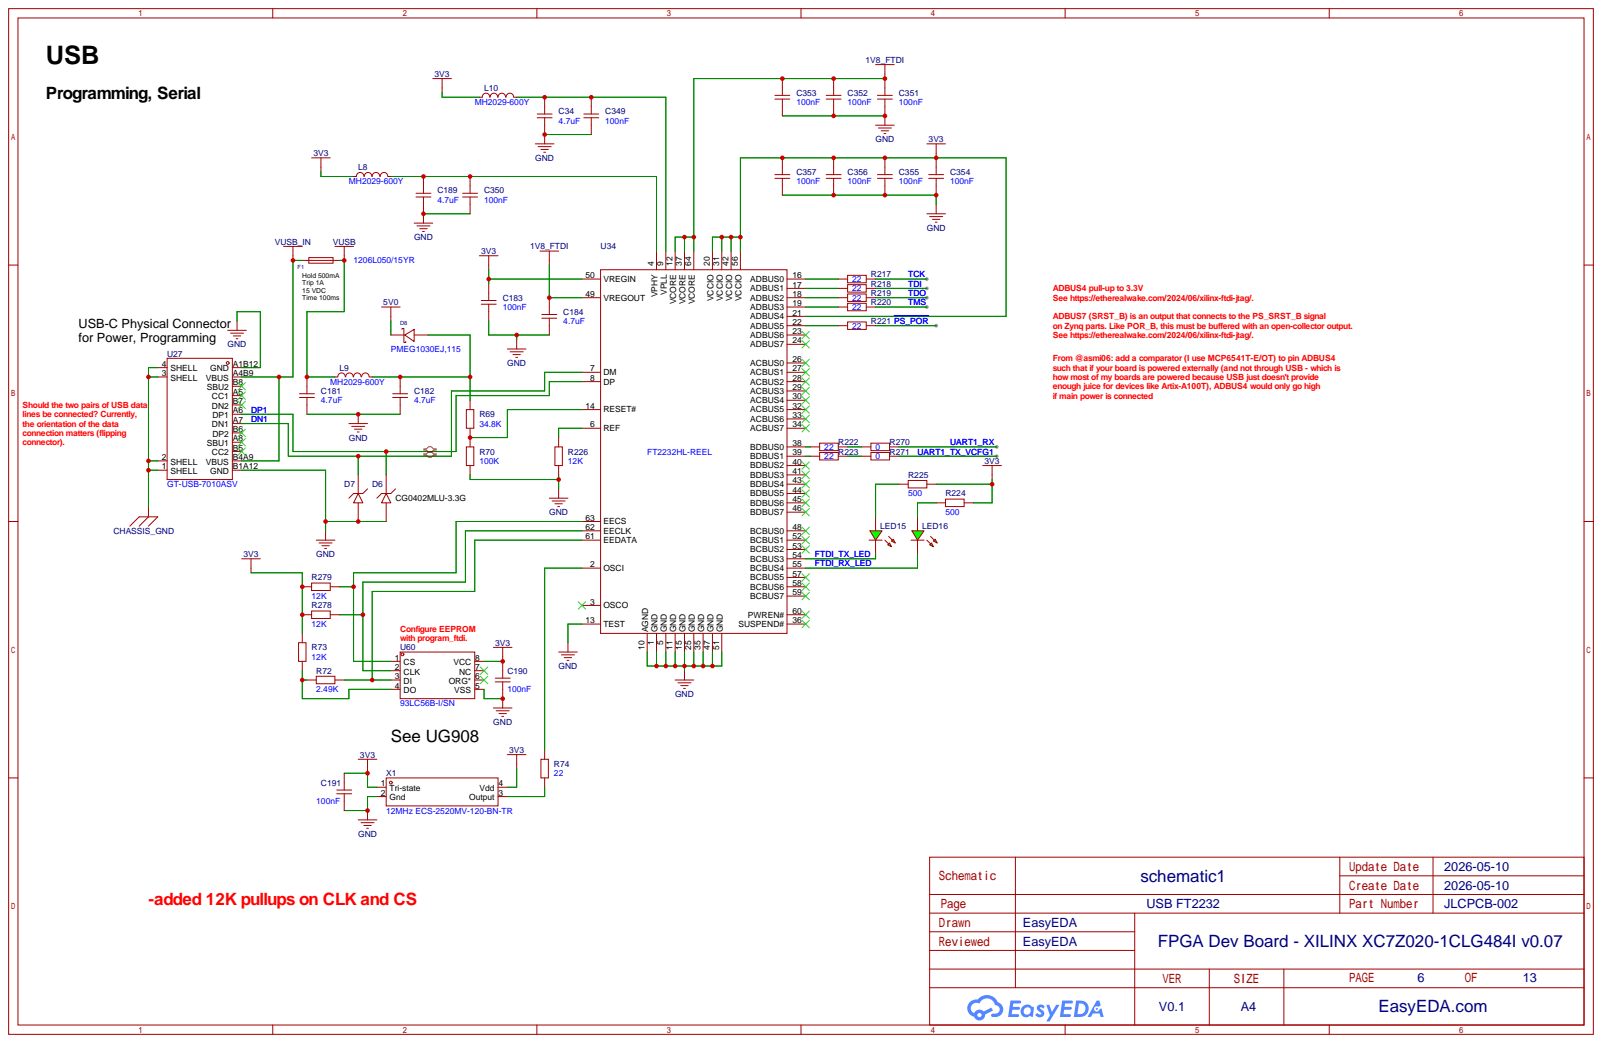
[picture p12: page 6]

ADBUS4 pull-up to 3.3V
See https://etherealwake.com/2024/06/xilinx-ftdi-jtag/.
ADBUS7 (SRST_B) is an output that connects to the PS_SRST_B signal
on Zynq parts. Like POR_B, this must be buffered with an open-collector output.

From @asmi06: add a comparator (I use MCP6541T-E/OT) to pin ADBUS4
such that if your board is powered externally (and not through USB - which is
how most of my boards are powered because USB just doesn't provide
enough juice for devices like Artix-A100T), ADBUS4 would only go high
if main power is connected

Should the two pairs of USB data
lines be connected? Currently,
the orientation of the data
connection matters (flipping
connector).

-added 12K pullups on CLK and CS

# USB OTG

# USB 2.0 ULPI PHY

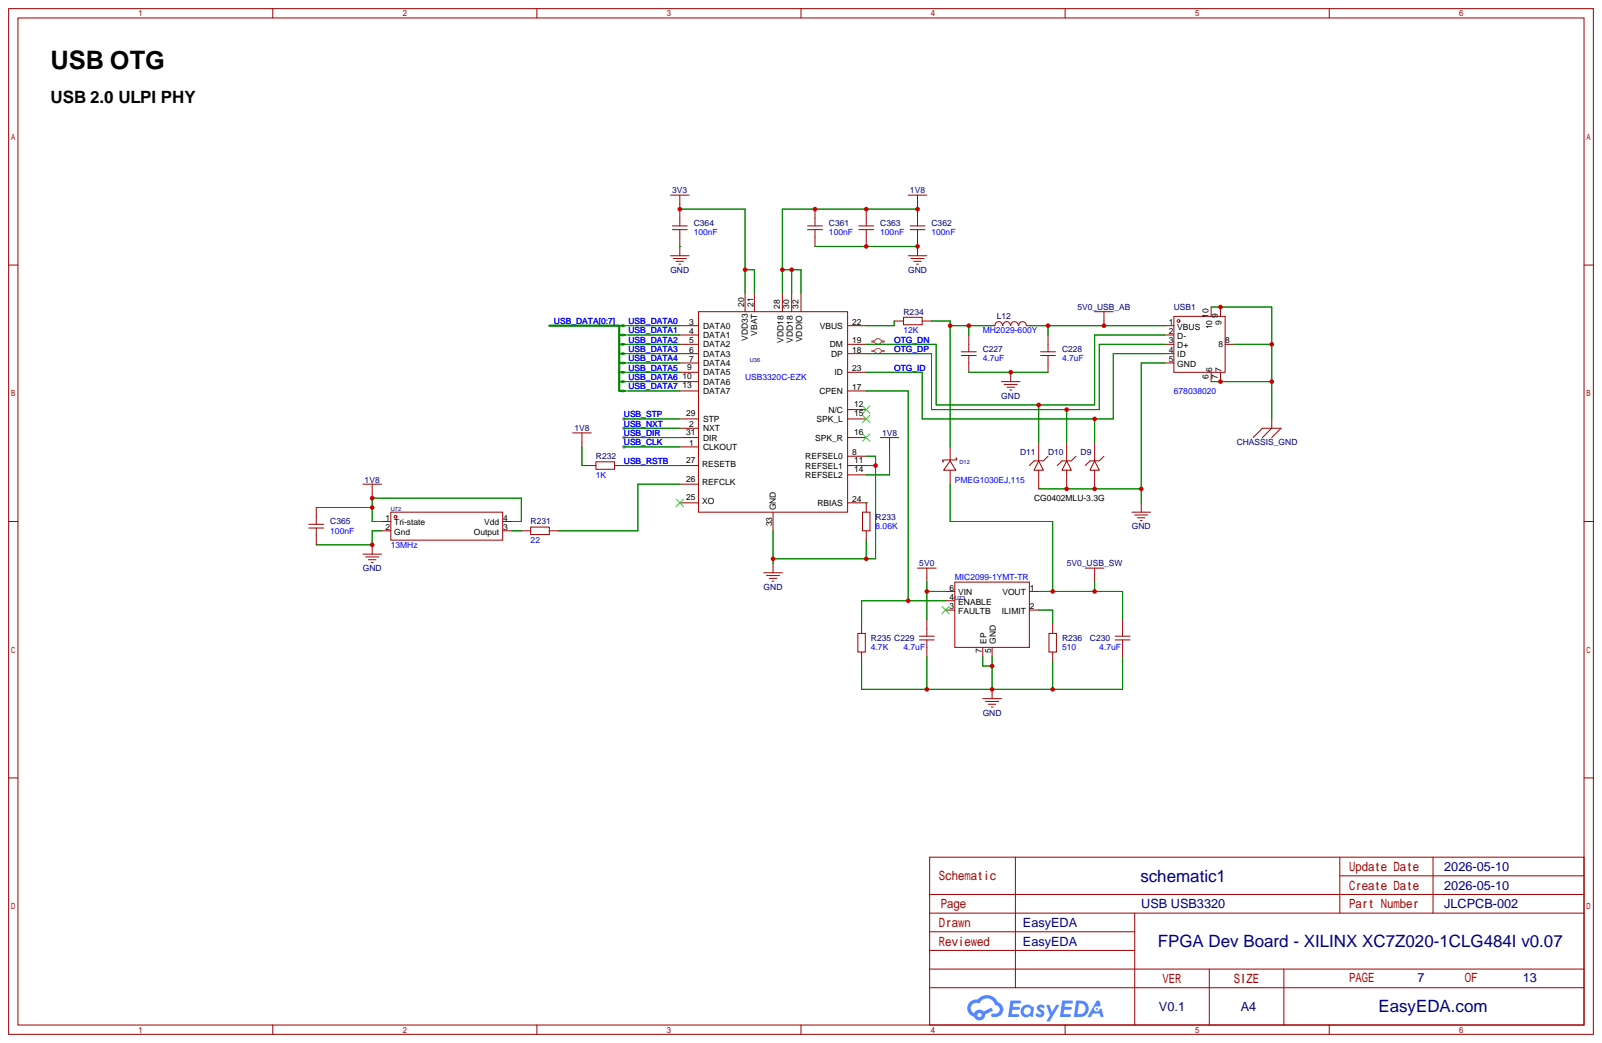
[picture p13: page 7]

# Ethernet

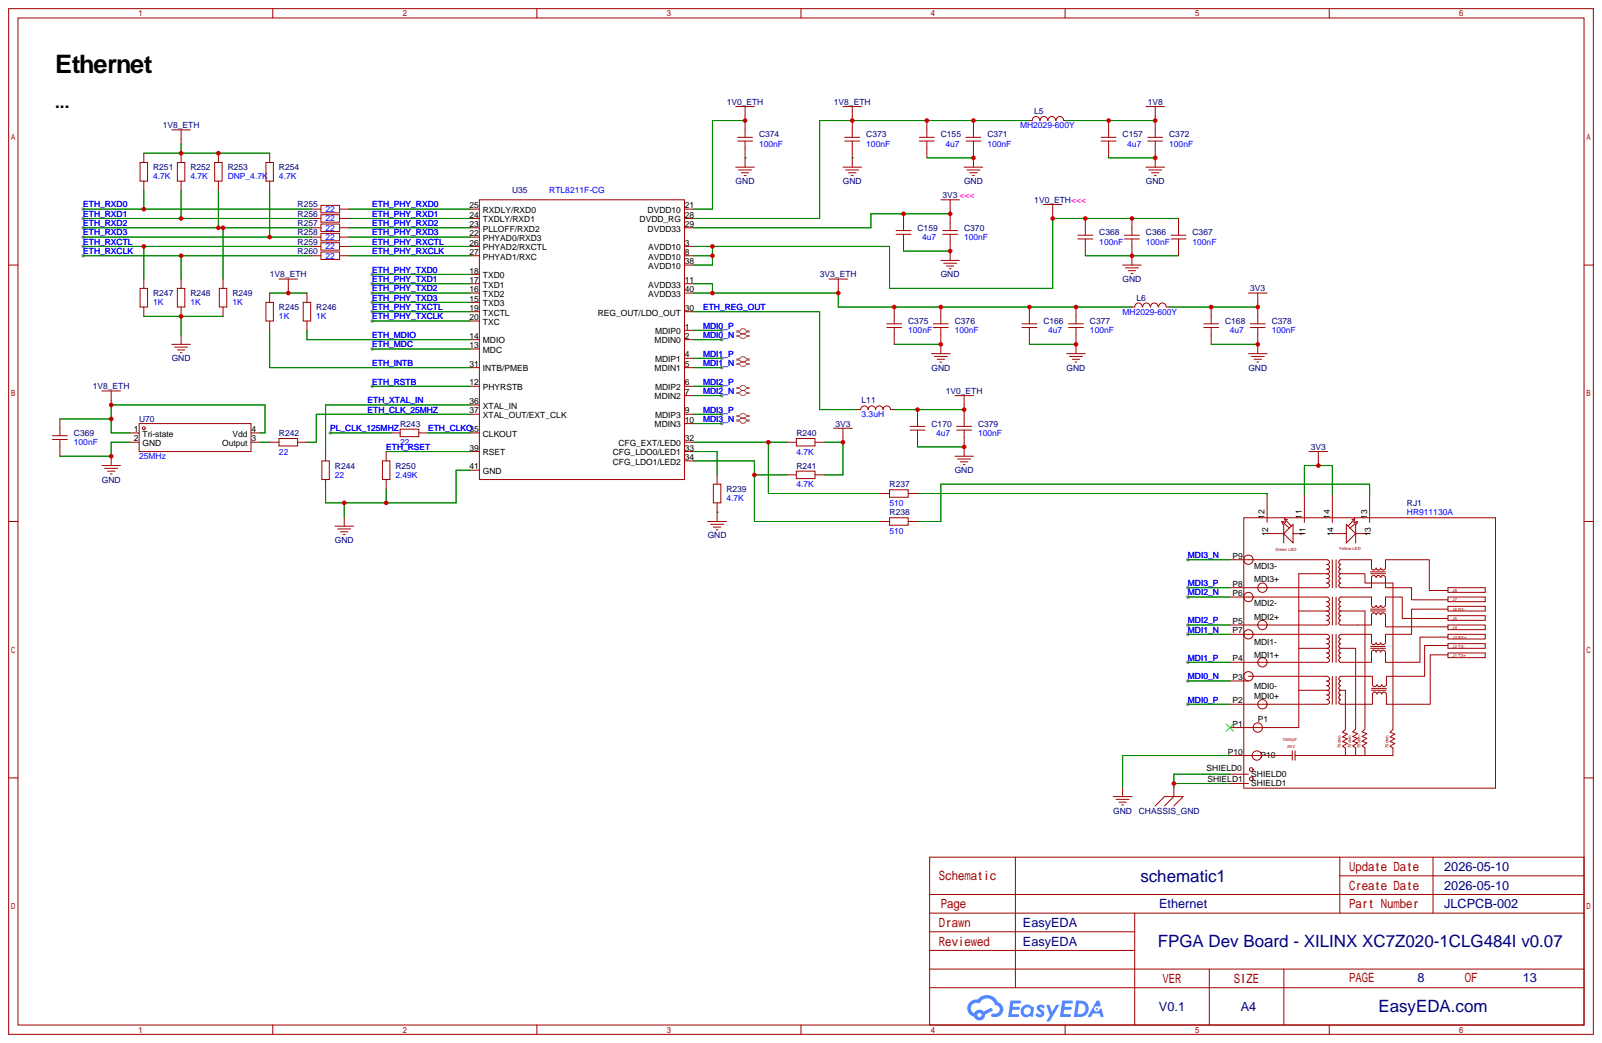
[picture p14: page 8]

# Processing System

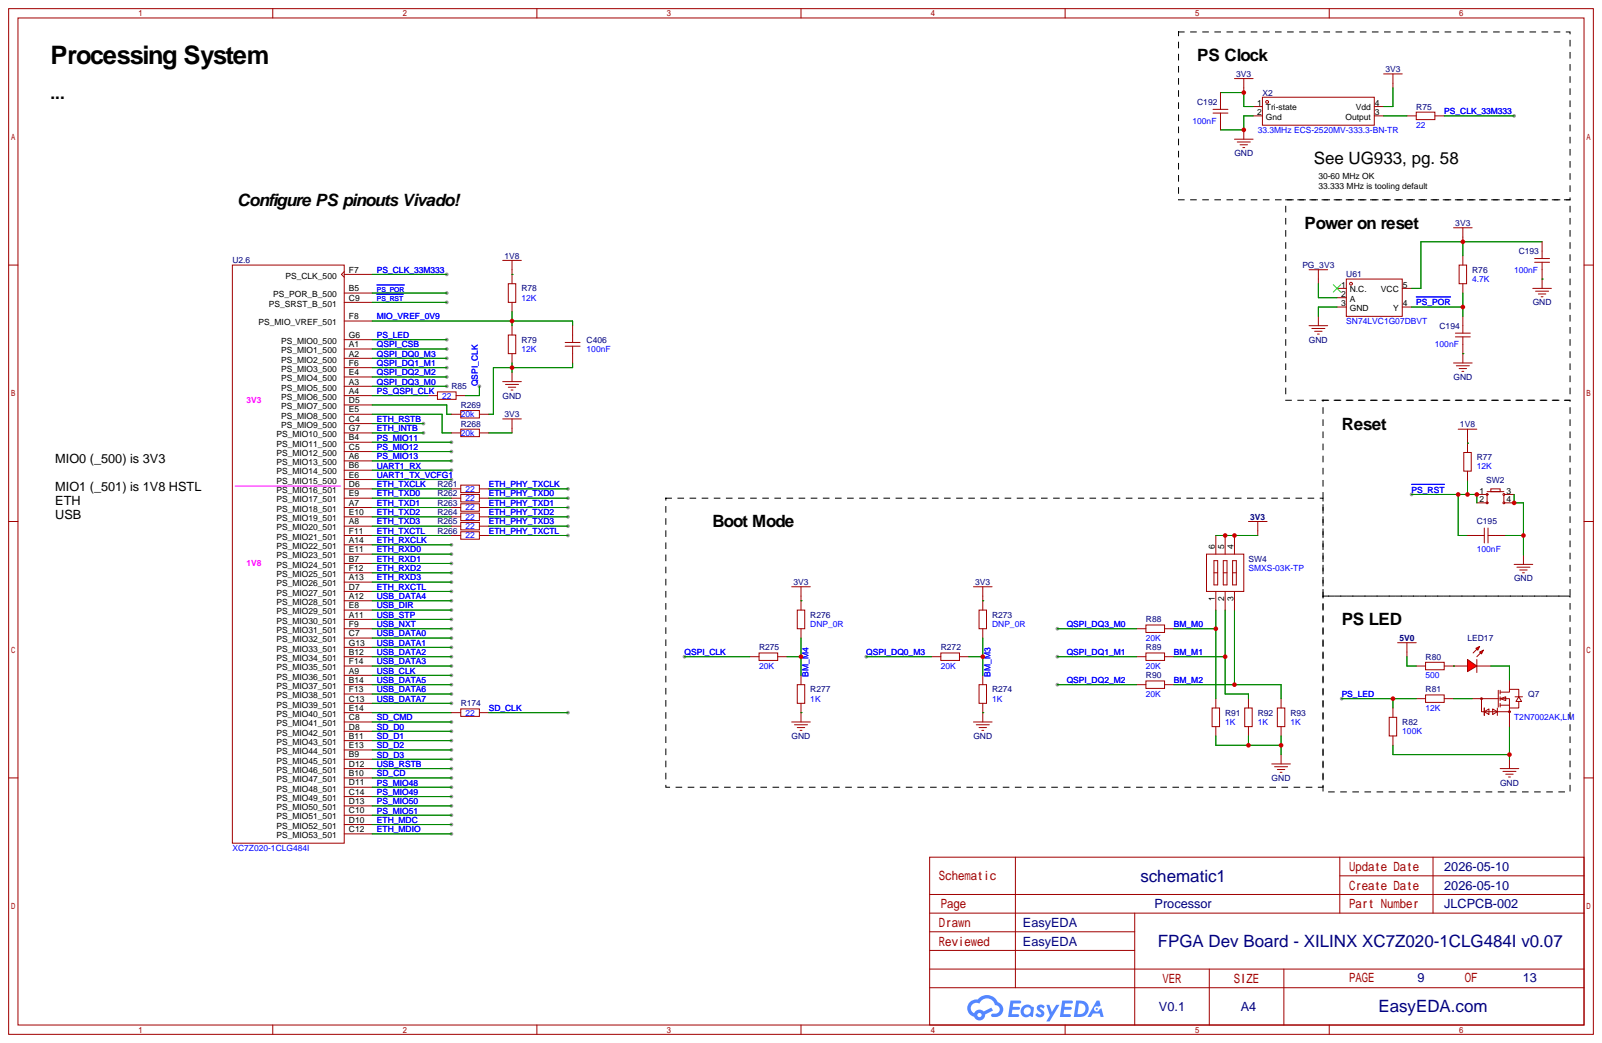
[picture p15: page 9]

30-60 MHz OK
33.333 MHz is tooling default
Power on reset

Configure PS pinouts Vivado!
PS_MIO53_501 C12 PS_MIO52_501 D10 PS_MIO51_501 C10 PS_MIO50_501 D13 PS_MIO49_501 C14 PS_MIO48_501 D11 PS_MIO47_501 B10 PS_MIO46_501 D12 PS_MIO45_501 B9 PS_MIO44_501 E13 PS_MIO43_501 B11 PS_MIO42_501 D8 PS_MIO41_501 C8 PS_MIO40_501 E14 PS_MIO39_501 C13 PS_MIO38_501 F13 PS_MIO37_501 B14 PS_MIO36_501 A9 PS_MIO35_501 F14 PS_MIO34_501 B12 PS_MIO33_501 G13 PS_MIO32_501 C7 PS_MIO31_501 F9 PS_MIO30_501 A11 PS_MIO29_501 E8 PS_MIO28_501 A12 PS_MIO27_501 D7 PS_MIO26_501 A13 PS_MIO25_501 F12 PS_MIO24_501 B7 PS_MIO23_501 E11 PS_MIO22_501 A14 PS_MIO21_501 F11 PS_MIO20_501 A8 PS_MIO19_501 E10 PS_MIO18_501 A7 PS_MIO17_501 E9 PS_MIO16_501 D6 PS_MIO15_500 E6 PS_MIO14_500 B6 PS_MIO13_500 A6 PS_MIO12_500 C5 PS_MIO11_500 B4 PS_MIO10_500 G7 PS_MIO9_500 C4 PS_MIO8_500 E5 PS_MIO7_500 D5 PS_MIO6_500 A4 PS_MIO5_500 A3 PS_MIO4_500 E4 PS_MIO3_500 F6 PS_MIO2_500 A2 PS_MIO1_500 A1 PS_MIO0_500 G6
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

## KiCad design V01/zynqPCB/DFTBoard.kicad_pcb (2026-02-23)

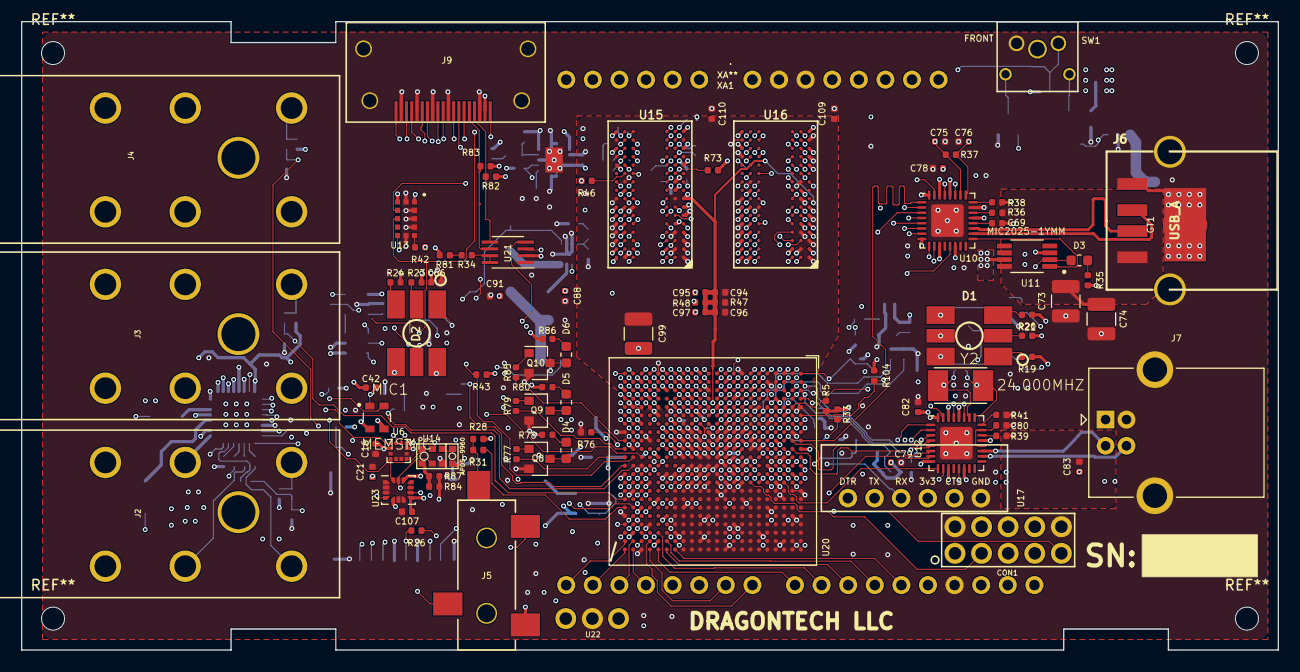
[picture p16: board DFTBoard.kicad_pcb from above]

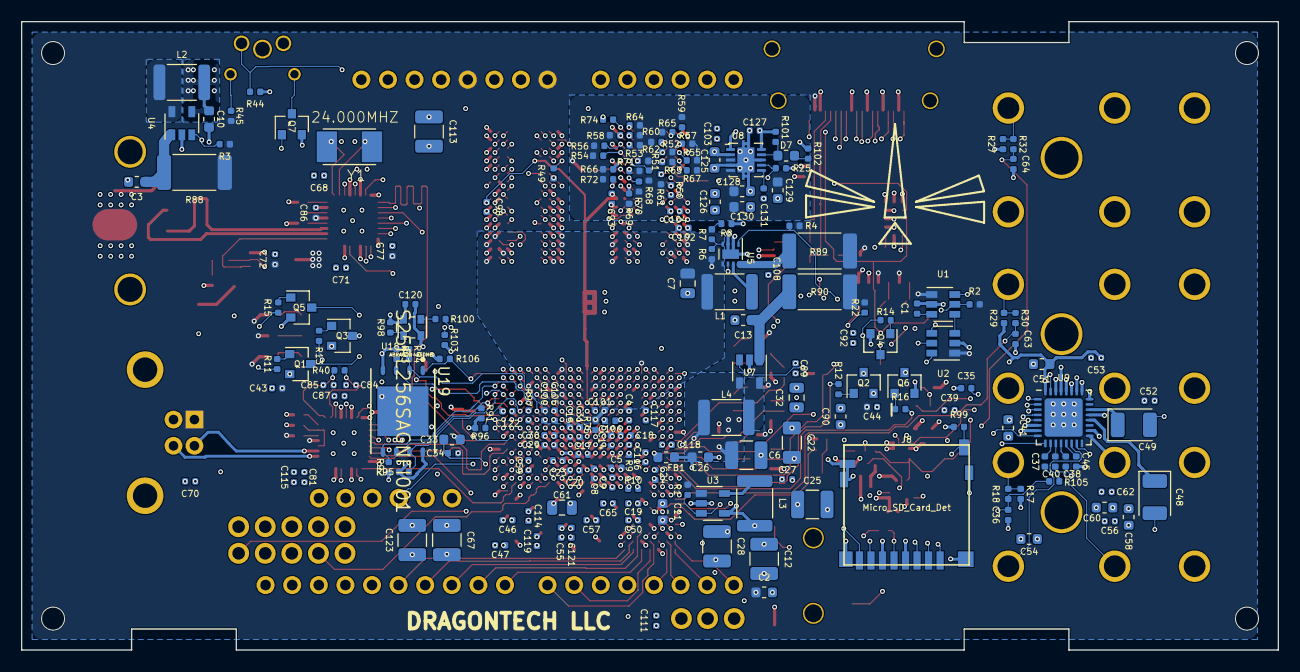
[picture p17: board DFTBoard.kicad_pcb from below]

Board: 8 copper layers, 120.0 x 60.0 mm, 295 parts (200 on the bottom side), 302 nets.

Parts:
C1, C4, C8, C14, C15, C17, C18, C23, C29, C30, C31, C34, C46, C47, C50, C55, C65, C78, C87, C101, C102, C103, C104, C108, C116, C117, C118, C119, C121: .47uF; C_0402_1005Metric
C2, C3, C10, C11, C13, C26, C33, C41, C51, C54, C58, C60, C90, C125, C126, C128, C129, C130: 10uF; C_0603_1608Metric
C5, C9, C19, C20, C21, C24, C27, C42, C57, C59, C66, C83, C89, C100, C114, C115, C122, C127: 4.7uF; C_0402_1005Metric
C6, C12, C25, C28, C67, C73, C74, C99, C123: 100uF; C_1210_3225Metric
C7, C32, C61: 47uF; C_0805_2012Metric
C16, C36, C39, C52, C53, C56, C62, C63, C64, C68, C70, C71, C72, C77, C79, C81, C82, C86, C88, C94, C95, C96, C97, C107, C131: .1uF; C_0402_1005Metric
C22: 330uF; C_1206_3216Metric
C35, C69, C80: 2.2uF; C_0402_1005Metric
C37, C38, C40, C43, C44, C45, C91, C92: 1uF; C_0402_1005Metric
C48, C49: 220uF Tant.; CP_EIA-3528-12_Kemet-T
C75, C76, C84, C85: 18pF; C_0402_1005Metric
C93, C98, C105, C106, C109, C110, C111, C120: .01uF; C_0402_1005Metric
C113: 47uF; C_1210_3225Metric
CON1: AVR-JTAG-10; XilinxJTAG
D1, D2: LED_RGB; PLCC6-SM-RGB-LED
D3, D4, D5, D6, D7: BLUE LED; C_0603_1608Metric
FB1: 120R, 100 MHz, size 0603; C_0603_1608Metric
GT1: GNDTIE; gndtie
J2, J3, J4: AUDIO JACK; RA49C14B
J5: JACK_TRS_4PINS; SJ-352X-SMT
J6: USB_A; USB-A-Receptacle-FCI_87583
J7: USB_B; USB_B_OST_USB-B1HSxx_Horizontal
J8: Micro_SD_Card_Det; AMPHENOL-114-00841-68
J9: HDMI_A; 10029449-111RLF
L1, L2, L3, L4: 2.2uH; C_1812_4532Metric
MIC1: MEMSMIC; MIC_SPW2430HR5H-B
Q1, Q2, Q3, Q4, Q5, Q6, Q7, Q8, Q9, Q10: IRLML2502; SOT-23
R1, R2, R3, R4, R5, R17, R27, R28, R29, R34, R81, R101: 100k; R_0402_1005Metric
R6, R33, R36, R39, R42, R43, R44: 10k; R_0402_1005Metric
R7, R46, R49: 240 1%; R_0402_1005Metric
R8, R9, R10, R74, R82, R83, R98, R103, R104: 4.7k; R_0402_1005Metric
R11, R12, R13, R14, R15, R16, R19, R20, R22, R23: 100; R_0402_1005Metric
R18, R30, R31, R32: 49.9k; R_0402_1005Metric
R21, R24, R35, R45, R78, R80, R86, R102: 150; R_0402_1005Metric
R25, R91, R92, R93, R94, R95, R96, R97, R106: 20k; R_0402_1005Metric
R26, R84, R87: 47; R_0402_1005Metric
R37, R40: 1M; R_0402_1005Metric
R38, R41: 8.06k 1%; R_0402_1005Metric
R47, R48: 10k 1%; R_0402_1005Metric
R50, R75, R76: 80.6 1%; R_0402_1005Metric
R51, R52, R53, R54, R55, R56, R57, R58, R59, R60, R61, R62, R63, R64, R65, R66, R67, R68, R69, R70, R71, R72, R73: 40.2 1%; R_0402_1005Metric
R77, R79, R85, R105: 1k; R_0402_1005Metric
R88, R89, R90: .05; R_2512_6332Metric
R99: 47k; R_0402_1005Metric
R100: 24.9 1%; R_0402_1005Metric
SW1: TL6215RF200BDT; tl6215_right_angle
U1, U2: LM3880; SOT-23-6
U3: SC189 - 1.0V; SOT-23-5
U4: SC189 - 3.3V; SOT-23-5
U5: TLV62080DSGx; WSON-8-1EP_2x2mm_P0.5mm_EP0.9x1.6mm
U6: LIS2HH12; LGA-12_2x2mm_P0.5mm
U7: SC189 - 1.8V; SOT-23-5
U8: TPS51200DRCR; VSON-10-1EP_3x3mm_P0.5mm_EP1.65x2.4mm_ThermalVias
U9: TLV320AIC3104; QFN-32-1EP_5x5mm_P0.5mm_EP3.65x3.65mm
U10, U12: USB3320; QFN-32-1EP_5x5mm_P0.5mm_EP3.1x3.1mm
U11: MIC2025-1YMM; SOP65P490X110-8N
U13: VL53L1CXV0FY/1; Optical_LGA12
U14: APDS-9960; APDS_9960
U15, U16: MT41K256M16HA-125_E; FBGA-96-DDR3-SDRAM
U17: FTDITypeUART; FTDI_CONN
U18: ABRACON-ASDMB; XTAL_ASDMB-24.000MHZ-LC-T
U19: S25FL256SAGNFI001; Cypress-002-18827-0-0-0
U20: xc7z020clg484; BGA-484_19.0x19.0mm_Layout22x22_P0.80mm_dia0.40mm
U21: PCA9306; SSOP-8_2.95x2.8mm_P0.65mm
U22: TSOP344; JUMPER_3PIN
U23: LSM6DSLTR; LGA-14_3x2.5mm_P0.5mm_LayoutBorder3x4y
XA1: Arduino_Uno_Shield_Simplified
Y1, Y2: 24.000MHZ; XTAL500X320X130N

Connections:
1v0en: R1.2, U1.6, U3.3
1v8en: R2.2, U1.5, U7.3
1v35PG: U5.6, U20.V4
1v35en: R4.2, U2.5, U5.1
3v3en: R3.2, U2.6, U4.3
+1V0: C8.1, C9.1, C11.1, C12.1, C23.1, C24.1, C25.1, C27.1, C28.1, C29.1, C30.1, C31.1, L3.2, U3.4, U20.G8, U20.H9, U20.H11, U20.J8, U20.J10, U20.J12, U20.J14, U20.K13, U20.L8, U20.L14, U20.M13, U20.N8, U20.N14, U20.P13, U20.R8, U20.R14
+1V8: C4.1, C5.1, C6.1, C14.1, C15.1, C17.1, C18.1, C19.1, C20.1, C22.1, C26.1, C32.1, C51.1, C53.1, C78.1, C87.1, CON1.4, FB1.2, L4.2, R9.2, R10.2, R17.1, R27.2, R28.2, R29.2, R44.1, U7.4, U9.32, U10.28, U10.30, U12.28, U12.30, U20.H10, U20.K9, U20.K11, U20.M9, U20.P9, U20.R12, U20.T7, U20.T8, U20.T9, U20.T10
+1V35: C7.1, C94.1, C96.1, C99.1, C100.1, C101.1, C102.1, C103.1, C104.1, C109.1, C110.1, C125.1, C126.1, L1.2, R6.2, R47.1, R75.2, U5.5, U8.2, U15.A1, U15.A8, U15.B2, U15.C1, U15.C9, U15.D2, U15.D9, U15.E9, U15.F1, U15.G7, U15.H2, U15.H9, U15.K2, U15.K8, U15.N1, U15.N9, U15.R1, U15.R9, U16.A1, U16.A8, U16.B2, U16.C1, U16.C9, U16.D2, U16.D9, U16.E9, U16.F1, U16.G7, U16.H2, U16.H9, U16.K2, U16.K8, U16.N1, U16.N9, U16.R1, U16.R9, U20.E2, U20.F5, U20.H1, U20.J4, U20.K7, U20.M3, U20.N6, U20.R2, U20.V1
+3V3: C10.1, C16.1, C21.1, C39.2, C41.2, C46.1, C47.1, C50.1, C52.2, C54.2, C55.1, C56.2, C57.1, C58.2, C59.1, C60.1, C61.1, C62.1, C65.1, C66.1, C67.1, C68.1, C70.1, C71.1, C79.1, C81.1, C82.1, C88.1, C89.1, C90.2, C91.2, C92.2, C107.1, C111.1, C113.1, C114.1, C115.1, C116.1, C117.1, C118.1, C119.1, C120.1, C121.1, C122.1, C123.1, C127.2, J8.4, L2.2, R5.1, R25.1, R33.2, R35.2, R42.1, R43.1, R82.1, R83.1, R84.2, R87.1, R95.2, R98.2, R99.1, R101.1, R102.2, R103.1, R104.1, R106.2, U4.4, U6.2, U6.9, U6.10, U8.10, U9.7, U9.18, U9.24, U9.25, U10.8, U10.11, U10.14, U10.32, U12.8, U12.11, U12.14, U12.32, U13.1, U13.11, U14.5, U17.3, U18.4, U19.8, U20.A10, U20.AA10, U20.AA20, U20.AB3, U20.AB13, U20.B3, U20.B13, U20.C6, U20.D9, U20.E12, U20.T5, U20.U8, U20.U18, U20.V11, U20.V21, U20.W4, U20.W14, U20.Y7, U20.Y17, U21.2, U22.3, U23.5, U23.8, U23.12, XA1.3V3, XA1.IORF
+5V: C2.1, C43.1, C44.1, C72.1, C77.1, C83.2, C86.1, J7.1, J9.18, R1.1, R2.1, R3.1, R4.1, R19.1, R20.1, R21.1, R22.1, R23.1, R24.1, R39.2, R45.1, R78.1, R80.2, R81.2, R86.2, R88.1, R89.1, R90.1, U1.1, U2.1, U3.1, U10.21, U11.7, U12.21, XA1.5V1, XA1.VIN
/Audio/HPRCOM_C_N: C48.2, J5.3
/Audio/HPRCOM_C_P: C49.2, J5.2
/Audio/HPSWITCH: J5.4, R28.1, R31.2
/Audio/INSWITCH: J2.TB, R17.2, R18.2
/Audio/JACK_INC_N: C40.1, U9.11
/Audio/JACK_INC_P: C37.1, U9.10
/Audio/JACK_IN_N: C40.2, J2.R
/Audio/JACK_IN_P: C37.2, J2.T
/Audio/LED_1BA: D1.3, R21.2
/Audio/LED_1BC: D1.4, Q5.3
/Audio/LED_1GA: D1.2, R20.2
/Audio/LED_1GC: D1.5, Q3.3
/Audio/LED_1RA: D1.1, R19.2
/Audio/LED_1RC: D1.6, Q1.3
/Audio/LED_2BA: D2.3, R24.2
/Audio/LED_2BC: D2.4, Q6.3
/Audio/LED_2GA: D2.2, R23.2
/Audio/LED_2GC: D2.5, Q4.3
/Audio/LED_2RA: D2.1, R22.2
/Audio/LED_2RC: D2.6, Q2.3
/Audio/LSWITCH: J3.TB, R29.1, R30.2
/Audio/MICBIAS: C35.2, C42.1, MIC1.1, U9.15
/Audio/RSWITCH: J4.TB, R27.1, R32.2
/Audio/SIGC_F: C38.2, MIC1.4
/Audio/SIG_F: C38.1, U9.12
/DDR3/PGOOD_LED: D7.2, R102.1
/DDR3/VREF: C93.1, C94.2, C95.1, C96.2, C97.1, C98.1, C105.1, C106.1, R47.2, R48.1, U8.1, U15.H1, U15.M8, U16.H1, U16.M8, U20.H7, U20.P7
/DDR3/ZQH: R46.1, U15.L8
/DDR3/ZQL: R49.1, U16.L8
/LCD50/SLED0_D: D4.1, Q8.3
/LCD50/SLED0_G: Q8.1, R77.1
/LCD50/SLED0_R: D4.2, R78.2
/LCD50/SLED1_D: D5.1, Q9.3
/LCD50/SLED1_G: Q9.1, R79.1
/LCD50/SLED1_R: D5.2, R80.1
/LCD50/SLED2_D: D6.1, Q10.3
/LCD50/SLED2_G: Q10.1, R85.1
/LCD50/SLED2_R: D6.2, R86.1
/Power/1V0TOLX: L3.1, U3.5
/Power/1V8TOLX: L4.1, U7.5
/Power/1V8_CS: C13.1, R90.2, U7.1
/Power/1V35_CS: C108.1, R89.2, U5.8
/Power/3V3TOLX: L2.1, U4.5
/Power/3V3_CS: C3.1, R88.2, U4.1
/Power/VCCAUX: C33.1, C34.1, FB1.1, U20.L10, U20.N10, U20.P11, U20.R10
/Sensors/3.3V_R: R84.1, R87.2, U14.8
/Sensors/TEMPO_LED_D: Q7.3, SW1.3
/Sensors/TEMPO_LED_R: R45.2, SW1.4
/USB/USBH_FLAG_LED: D3.2, R35.1
ACC_INT1: U6.12, U20.W12
ACC_INT2: U6.11, U20.V12
AX_TCLK: CON1.1, U20.G11
AX_TDI: CON1.9, U20.H13
AX_TDO: CON1.3, U20.G14
AX_TMS: CON1.5, U20.G12
BOOTSPI_CS: R106.1, U19.1, U20.A1
BOOTSPI_DQ0_BMODE3: R92.1, U19.5, U20.A2
BOOTSPI_DQ1_BMODE1: R94.1, U19.2, U20.F6
BOOTSPI_DQ2_BMODE2: R93.1, U19.3, U20.E4
BOOTSPI_DQ3_BMODE0: R95.1, U19.7, U20.A3
BOOTSPI_SCK_BMODE4: R91.1, U19.6, U20.A4
CLK33.33: R100.2, U18.3
DDR3_A0: R51.1, U15.N3, U16.N3, U20.M4
DDR3_A1: R52.1, U15.P7, U16.P7, U20.M5
DDR3_A2: R53.1, U15.P3, U16.P3, U20.K4
DDR3_A3: R54.1, U15.N2, U16.N2, U20.L4
DDR3_A4: R55.1, U15.P8, U16.P8, U20.K6
DDR3_A5: R56.1, U15.P2, U16.P2, U20.K5
DDR3_A6: R57.1, U15.R8, U16.R8, U20.J7
DDR3_A7: R58.1, U15.R2, U16.R2, U20.J6
DDR3_A8: R59.1, U15.T8, U16.T8, U20.J5
DDR3_A9: R60.1, U15.R3, U16.R3, U20.H5
DDR3_A10: R61.1, U15.L7, U16.L7, U20.J3
DDR3_A11: R62.1, U15.R7, U16.R7, U20.G5
DDR3_A12: R63.1, U15.N7, U16.N7, U20.H4
DDR3_A13: R64.1, U15.T3, U16.T3, U20.F4
DDR3_A14: R65.1, U15.T7, U16.T7, U20.G4
DDR3_BA0: R66.1, U15.M2, U16.M2, U20.L7
DDR3_BA1: R67.1, U15.N8, U16.N8, U20.L6
DDR3_BA2: R68.1, U15.M3, U16.M3, U20.M6
DDR3_CAS#: R70.1, U15.K3, U16.K3, U20.P3
DDR3_CKE: U15.K9, U16.K9, U20.V3
DDR3_CK_N: R50.2, U15.K7, U16.K7, U20.N5
DDR3_CK_P: R50.1, U15.J7, U16.J7, U20.N4
DDR3_CS#: R73.1, U15.L2, U16.L2, U20.P6
DDR3_DM0: U16.E7, U20.B1
DDR3_DM1: U16.D3, U20.H3
DDR3_DM2: U15.E7, U20.P1
DDR3_DM3: U15.D3, U20.AA2
DDR3_DQ0: U16.E3, U20.C3
DDR3_DQ1: U16.F7, U20.F2
DDR3_DQ2: U16.F2, U20.B2
DDR3_DQ3: U16.F8, U20.F1
DDR3_DQ4: U16.H3, U20.E3
DDR3_DQ5: U16.H8, U20.E1
DDR3_DQ6: U16.G2, U20.D3
DDR3_DQ7: U16.H7, U20.D1
DDR3_DQ8: U16.D7, U20.L3
DDR3_DQ9: U16.C3, U20.L1
DDR3_DQ10: U16.C8, U20.L2
DDR3_DQ11: U16.C2, U20.J1
DDR3_DQ12: U16.A7, U20.K1
DDR3_DQ13: U16.A2, U20.G2
DDR3_DQ14: U16.B8, U20.K3
DDR3_DQ15: U16.A3, U20.G1
DDR3_DQ16: U15.E3, U20.T3
DDR3_DQ17: U15.F7, U20.T1
DDR3_DQ18: U15.F2, U20.M1
DDR3_DQ19: U15.F8, U20.T2
DDR3_DQ20: U15.H3, U20.M2
DDR3_DQ21: U15.H8, U20.R1
DDR3_DQ22: U15.G2, U20.N3
DDR3_DQ23: U15.H7, U20.R3
DDR3_DQ24: U15.D7, U20.AA3
DDR3_DQ25: U15.C3, U20.Y1
DDR3_DQ26: U15.C8, U20.Y3
DDR3_DQ27: U15.C2, U20.W1
DDR3_DQ28: U15.A7, U20.AA1
DDR3_DQ29: U15.A2, U20.U1
DDR3_DQ30: U15.B8, U20.W3
DDR3_DQ31: U15.A3, U20.U2
DDR3_DQS0_N: U16.G3, U20.D2
DDR3_DQS0_P: U16.F3, U20.C2
DDR3_DQS1_N: U16.B7, U20.J2
DDR3_DQS1_P: U16.C7, U20.H2
DDR3_DQS2_N: U15.G3, U20.P2
DDR3_DQS2_P: U15.F3, U20.N2
DDR3_DQS3_N: U15.B7, U20.W2
DDR3_DQS3_P: U15.C7, U20.V2
DDR3_DRST#: R74.1, U15.T2, U16.T2, U20.F3
DDR3_ODT: R72.1, U15.K1, U16.K1, U20.P5
DDR3_RAS#: R69.1, U15.J3, U16.J3, U20.R5
DDR3_VTT: C128.1, C129.1, C130.1, R51.2, R52.2, R53.2, R54.2, R55.2, R56.2, R57.2, R58.2, R59.2, R60.2, R61.2, R62.2, R63.2, R64.2, R65.2, R66.2, R67.2, R68.2, R69.2, R70.2, R71.2, R72.2, R73.2, U8.3, U8.5
DDR3_VTT_EN: R25.2, U8.7, U20.B6
DDR3_WE#: R71.1, U15.L3, U16.L3, U20.R4
GND: C1.2, C2.2, C3.2, C4.2, C5.2, C6.2, C7.2, C8.2, C9.2, C10.2, C11.2, C12.2, C13.2, C14.2, C15.2, C16.2, C17.2, C18.2, C19.2, C20.2, C21.2, C22.2, C23.2, C24.2, C25.2, C26.2, C27.2, C28.2, C29.2, C30.2, C31.2, C32.2, C33.2, C34.2, C36.1, C39.1, C41.1, C43.2, C44.2, C46.2, C47.2, C50.2, C51.2, C53.2, C55.2, C57.2, C59.2, C61.2, C63.2, C64.2, C65.2, C66.2, C67.2, C68.2, C69.1, C70.2, C71.2, C72.2, C73.1, C74.1, C75.1, C76.1, C77.2, C78.2, C79.2, C80.1, C81.2, C82.2, C83.1, C84.1, C85.1, C86.2, C87.2, C88.2, C89.2, C90.1, C91.1, C92.1, C93.2, C95.2, C97.2, C98.2, C99.2, C100.2, C101.2, C102.2, C103.2, C104.2, C105.2, C106.2, C107.2, C108.2, C109.2, C110.2, C111.2, C113.2, C114.2, C115.2, C116.2, C117.2, C118.2, C119.2, C120.2, C121.2, C122.2, C123.2, C125.2, C126.2, C127.1, C128.2, C129.2, C130.2, C131.2, CON1.2, CON1.10, GT1.1, J6.4, J6.5, J7.4, J7.5, J8.6, J8.10, J8.11, J9.2, J9.5, J9.8, J9.11, J9.17, J9.SH, Q1.2, Q2.2, Q3.2, Q4.2, Q5.2, Q6.2, Q7.2, Q8.2, Q9.2, Q10.2, R8.2, R38.2, R41.2, R46.2, R48.2, R49.2, R74.2, R76.2, R91.2, R92.2, R93.2, R94.2, R96.2, R97.2, SW1.1, U1.2, U2.2, U3.2, U4.2, U5.2, U5.3, U5.9, U6.3, U6.5, U6.6, U6.7, U6.8, U7.2, U8.4, U8.8, U8.11, U9.6, U10.23, U10.33, U11.3, U12.33, U13.2, U13.3, U13.4, U13.6, U13.12, U14.6, U15.A9, U15.B1, U15.B3, U15.B9, U15.D1, U15.D8, U15.E1, U15.E2, U15.E8, U15.F9, U15.G1, U15.G8, U15.G9, U15.J2, U15.J8, U15.M1, U15.M9, U15.P1, U15.P9, U15.T1, U15.T9, U16.A9, U16.B1, U16.B3, U16.B9, U16.D1, U16.D8, U16.E1, U16.E2, U16.E8, U16.F9, U16.G1, U16.G8, U16.G9, U16.J2, U16.J8, U16.M1, U16.M9, U16.P1, U16.P9, U16.T1, U16.T9, U17.1, U18.2, U19.4, U19.9, U20.A5, U20.A15, U20.A16, U20.A17, U20.A18, U20.A19, U20.A20, U20.A21, U20.A22, U20.AA5, U20.AA15, U20.AB8, U20.AB18, U20.B8, U20.B15, U20.B16, U20.B17, U20.B18, U20.B19, U20.B20, U20.B21, U20.B22, U20.C1, U20.C11, U20.C15, U20.C16, U20.C17, U20.C18, U20.C19, U20.C20, U20.C21, U20.C22, U20.D4, U20.D14, U20.D15, U20.D16, U20.D17, U20.D18, U20.D19, U20.D20, U20.D21, U20.D22, U20.E7, U20.E15, U20.E16, U20.E17, U20.E18, U20.E19, U20.E20, U20.E21, U20.E22, U20.F10, U20.F15, U20.F16, U20.F17, U20.F18, U20.F19, U20.F20, U20.F21, U20.F22, U20.G3, U20.G9, U20.G10, U20.G15, U20.G16, U20.G17, U20.G18, U20.G19, U20.G20, U20.G21, U20.G22, U20.H6, U20.H8, U20.H12, U20.H14, U20.H15, U20.H16, U20.H17, U20.H18, U20.H19, U20.H20, U20.H21, U20.H22, U20.J9, U20.J11, U20.J13, U20.J15, U20.J16, U20.J17, U20.J18, U20.J19, U20.J20, U20.J21, U20.J22, U20.K2, U20.K8, U20.K10, U20.K12, U20.K14, U20.K15, U20.K16, U20.K17, U20.K18, U20.K19, U20.K20, U20.K21, U20.K22, U20.L5, U20.L9, U20.L11, U20.L12, U20.L13, U20.L15, U20.L16, U20.L17, U20.L18, U20.L19, U20.L20, U20.L21, U20.L22, U20.M8, U20.M10, U20.M11, U20.M12, U20.M14, U20.M15, U20.M16, U20.M17, U20.M18, U20.M19, U20.M20, U20.M21, U20.M22, U20.N1, U20.N9, U20.N11, U20.N12, U20.N13, U20.N15, U20.N16, U20.N17, U20.N18, U20.N19, U20.N20, U20.N21, U20.N22, U20.P4, U20.P8, U20.P10, U20.P12, U20.P14, U20.P15, U20.P16, U20.P17, U20.P18, U20.P19, U20.P20, U20.P21, U20.P22, U20.R9, U20.R11, U20.R13, U20.R15, U20.R16, U20.R17, U20.R18, U20.R19, U20.R20, U20.R21, U20.R22, U20.T13, U20.T15, U20.T16, U20.T17, U20.T18, U20.T19, U20.T20, U20.U3, U20.U13, U20.V6, U20.V16, U20.W9, U20.W19, U20.Y2, U20.Y12, U20.Y22, U21.1, U22.2, U23.1, U23.2, U23.3, U23.6, U23.7, XA1.GND1, XA1.GND2, XA1.GND3
GNDA: C35.1, C42.2, C45.1, C52.1, C54.1, C56.1, C58.1, C60.2, C62.2, GT1.2, J2.RB, J2.S, J3.RB, J3.S, J4.RB, J4.S, J5.1, MIC1.2, MIC1.3, U9.17, U9.21, U9.26, U9.33
HDMI_B_N: J9.3, U20.AA8
HDMI_B_P: J9.1, U20.AA9
HDMI_CEC: J9.13, U20.W5
HDMI_CLK_N: J9.12, U20.Y8
HDMI_CLK_P: J9.10, U20.Y9
HDMI_G_N: J9.6, U20.AA6
HDMI_G_P: J9.4, U20.AA7
HDMI_HEAC_N: J9.19, U20.AB6
HDMI_HEAC_P: J9.14, U20.AB7
HDMI_R_N: J9.9, U20.Y5
HDMI_R_P: J9.7, U20.Y6
HPCOM_N: C48.1, U9.20
HPCOM_P: C49.1, U9.22
I2C5_HDMI_SCLK: J9.15, R83.2, U21.6
I2C5_HDMI_SDA: J9.16, R82.2, U21.5
I2C33_HDMI_SCLK: U20.U9, U21.3
I2C33_HDMI_SDA: U20.U10, U21.4
I2C33_SCLK: R103.2, U6.1, U9.8, U13.10, U14.7, U20.C5, U23.13
I2C33_SDA: R104.2, U6.4, U9.9, U13.9, U14.1, U20.A6, U23.14
I2S_ADCSD: U9.5, U20.AB15
I2S_BCLK: U9.2, U20.AA13
I2S_DACSD: U9.4, U20.AA14
I2S_LRCLK: U9.3, U20.AB14
I2S_MCLK: U9.1, U20.Y13
IMU_INT1: U20.W15, U23.4
IMU_INT2: U20.Y15, U23.9
INIT_B: R10.1, U20.T14
IR_RX: U20.AA18, U22.1
JD_HOUT: R31.1, U20.AB17
JD_IN: C36.2, R18.1, R105.2, U20.W17
JD_LOUT: C63.1, R30.1, U20.AB16
JD_ROUT: C64.1, R32.1, U20.AB19
LCD_D0: U20.AB21, XA1.D0
LCD_D1: U20.AB22, XA1.D1
LCD_D2: U20.U19, XA1.SCL
LCD_D3: U20.W20, XA1.SDA
LCD_D4: U20.V5, XA1.A5
LCD_D5: U20.AB5, XA1.A4
LCD_D6: U20.AB4, XA1.A3
LCD_D7: U20.AA4, XA1.A2
LCD_D8: U20.Y4, XA1.A1
LCD_D9: U20.AB2, XA1.A0
LCD_D10: U20.U20, XA1.AREF
LCD_D11: U20.AA21, XA1.D2
LCD_D12: U20.AA22, XA1.D3
LCD_D13: U20.Y21, XA1.D4
LCD_D14: U20.Y20, XA1.D5
LCD_D15: U20.W22, XA1.D6
LCD_D16: U20.W21, XA1.D7
LCD_D17: U20.V22, XA1.D8
LCD_D18: U20.V20, XA1.D9
LCD_D19: U20.U22, XA1.D10
LCD_D20: U20.U21, XA1.D11
LCD_D21: U20.T22, XA1.D12
LCD_D22: U20.T21, XA1.D13
LCD_D23: U20.AB1, XA1.RST1
LED_1B_CTRL: R15.2, U20.Y19
LED_1G_CTRL: R13.2, U20.AB20
LED_1R_CTRL: R11.2, U20.AA19
LED_2B_CTRL: R16.2, U20.AA12
LED_2G_CTRL: R14.2, U20.Y11
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

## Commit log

2026-02-23 import pcb design
    [Audio.kicad_sch, Audio.sch, DDR3.kicad_sch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]
2026-02-25 Update audio schematic
    [Audio.kicad_sch, DDR3.kicad_sch, LCD50.kicad_sch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]
2026-05-10 Prettify and added the final and new pcb
    [Audio.kicad_sch, Audio.sch, BOM_Board1_PCB1_2026-05-10.xlsx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]
2026-05-13 updated bom
    [BOM_Board1_PCB1_2026-05-10.xlsx, BOM_Board1_PCB1_2026-05-13.xlsx, PickAndPlace_PCB1_2026-05-10.xlsx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]
